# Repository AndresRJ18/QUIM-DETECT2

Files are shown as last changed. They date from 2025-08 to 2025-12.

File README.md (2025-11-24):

# QUIM-DETECT2  🍓🍓🍓
### Sistema Portátil de Detección de Pesticidas en Fresas mediante Espectroscopía VIS/NIR  

**QUIM-DETECT2** es un proyecto de investigación aplicada orientado al desarrollo de un **dispositivo portátil, económico y no destructivo** para la detección del pesticida organofosforado **Profenofos** en fresas, utilizando **espectroscopía de reflexión VIS/NIR (350–1000 nm)** y **análisis multivariante con Machine Learning**.  

El proyecto se alinea con el **Objetivo de Desarrollo Sostenible (ODS) 12: Producción y Consumo Responsables**, específicamente con la meta 12.4, cual busca reducir los impactos negativos de sustancias químicas peligrosas a lo largo de su ciclo de vida., promoviendo la gestión ecológica de productos químicos agrícolas y la reducción de riesgos para la salud humana y el medio ambiente.  

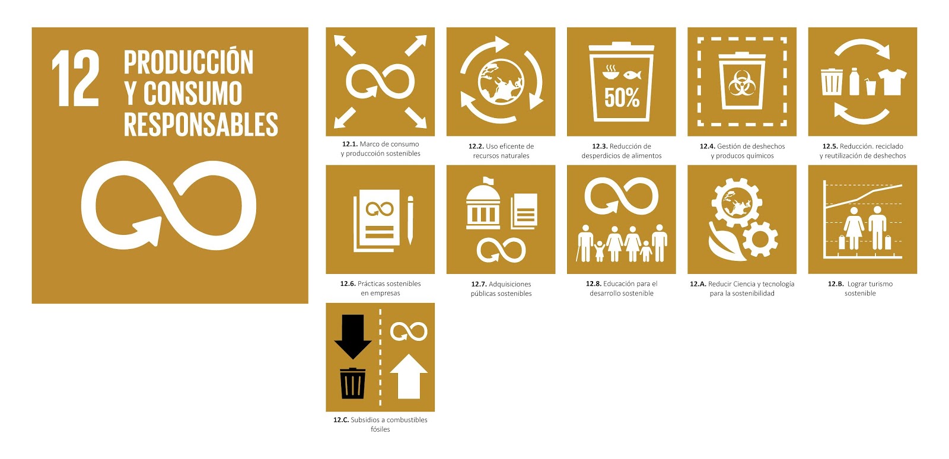
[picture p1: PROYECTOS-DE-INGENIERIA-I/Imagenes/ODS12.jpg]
ODS12


---

## 🎯 Objetivo General  

Desarrollar un **sistema portátil de bajo costo** capaz de identificar la presencia de residuos de *Profenofos* en fresas mediante la caracterización de su huella espectral.

---

## ⚙️ Componentes Principales  

- **Sensor óptico:** AS7343 (VIS/NIR 350–1000 nm, 18 canales espectrales).  
- **Módulo mecánico:** Servomotor y motor a paso para rotación controlada de la fresa y promediado espectral.  
- **Calibración:** Placa de teflón blanco (~97% reflectancia) o superficie blanca estandarizada.  
- **Carcasa y óptica:** Caja rígida con sellado óptico, ventana desmontable y compartimentos separados para electrónica y óptica.  
- **Procesamiento:** Algoritmos de Machine Learning (SVM, Random Forest, ANN) para clasificación de muestras contaminadas vs. no contaminadas.  

---

## 🧠 Metodología  

1. **Captura espectral:** Adquisición multicanal en el rango 400–1050 nm.  
2. **Preprocesamiento:** Filtrado de ruido, normalización, PCA y eliminación de outliers.  
3. **Entrenamiento ML:** Modelos supervisados para detección de residuos de *Profenofos*.  
4. **Validación:** Comparación frente a espectrómetros comerciales (PS-100, Apogee Instruments) y referencias científicas (*Soltani Nazarloo et al., 2021*).  

---

## 🧩 Diseño del Sistema  

- Diseño **modular** y de **mantenimiento rápido**.  
- **Ventana óptica desmontable** para limpieza y reemplazo.  
- **Superficies lisas y sellado óptico** para evitar contaminación de luz o humedad.  
- **Protección eléctrica** mediante fusibles y aisladores.  
- **Soporte fijo** con servomotor que mantiene distancia constante entre la muestra y el sensor.  

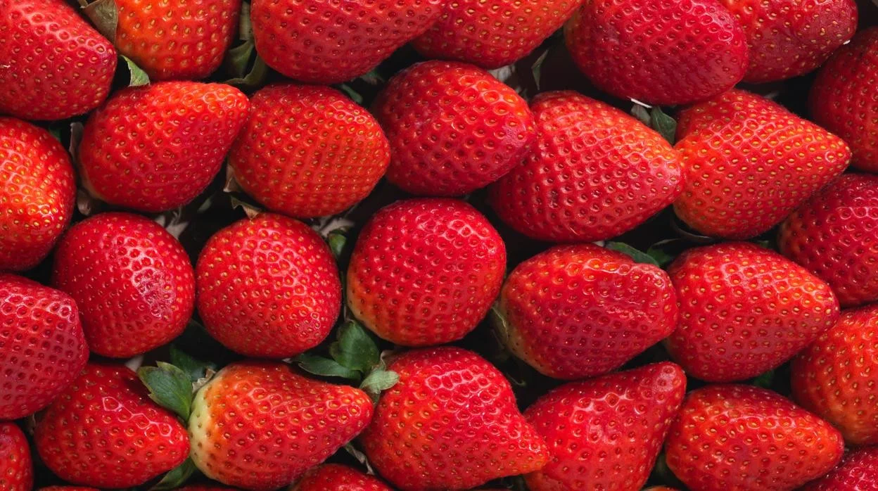
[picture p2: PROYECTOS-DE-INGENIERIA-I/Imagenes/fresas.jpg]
Fresas


---

## 🧪 Referencias Científicas  

- Soltani Nazarloo, A., et al. (2021). *Feasibility of Using VIS/NIR Spectroscopy and Multivariate Analysis for Pesticide Residue Detection in Tomatoes.*  
- Apogee Instruments PS-100 – Compact VIS/NIR Spectrometer (350–1100 nm).  

---

## 👥 Equipo de Trabajo  

- **Matias Dario Huerta Cruz**  
- **Andres Steven Rodas Janampa**  
- **Jorge Esteban Roldan Montalvan**  
- **Juan Diego Lopez Vega**  
- **Camilla Vanessa Pacora Mendoza**  

---

## 🎓 Proyecto Académico  

Proyecto desarrollado para el curso **Proyectos de Ingeniería I – 2025-II**  
**Universidad Peruana Cayetano Heredia (UPCH)**  
Facultad de Ciencias e Ingeniería – **Carrera de Ingeniería Informática**

---

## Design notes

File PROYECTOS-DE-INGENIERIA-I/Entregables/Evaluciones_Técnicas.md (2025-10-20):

#  Análisis Tecnológico 

| **Subfunción** | **Boceto 1 – Cámara multiespectral** | **Boceto 2 – Escáner UV con pantalla** | **Boceto 3 – Sistema AS7343 con caja giratoria** |
|---|---|---|---|
| **Rotar fresa / toma de muestra** | No aplica (captura fija) | Sin movimiento | Motor paso a paso con brazo rotable |
| **Detección** | Cámara multiespectral de alta gama | LED UV + fotodiodo TEMP6000 | Sensor AS7343 visible/NIR |
| **Control y adquisición** | Raspberry Pi | ESP32 | Arduino Nano 33 IoT |
| **Procesamiento de datos** | Software propietario | Pantalla LCD con lógica simple | Google Colab (Python) |
| **Energía** | Batería Li-ion 7.4V | Batería recargable 5V | Batería 18650 |

---

##  Criterios de Evaluación Tecnológica

| **Criterio** | **Peso** |
|---|---|
| Precisión de medición | 0.30 |
| Costo total | 0.25 |
| Complejidad técnica (menor = mejor) | 0.15 |
| Mantenimiento y calibración | 0.15 |
| Robustez y fiabilidad | 0.10 |
| Consumo energético | 0.05 |
| **Total** | **1.00** |

---

###  Ponderación de los 3 Bocetos

| **Criterio** | **Peso** | **Boceto 1** | **Boceto 2** | **Boceto 3** | **P*B1** | **P*B2** | **P*B3** |
|---|---|---|---|---|---|---|---|
| Precisión | 0.30 | 5 | 3 | 4 | 1.50 | 0.90 | 1.20 |
| Costo | 0.25 | 1 | 4 | 5 | 0.25 | 1.00 | 1.25 |
| Complejidad | 0.15 | 2 | 3 | 4 | 0.30 | 0.45 | 0.60 |
| Mantenimiento | 0.15 | 3 | 4 | 4 | 0.45 | 0.60 | 0.60 |
| Robustez | 0.10 | 3 | 3 | 4 | 0.30 | 0.30 | 0.40 |
| Consumo | 0.05 | 2 | 3 | 4 | 0.10 | 0.15 | 0.20 |
| **Total ponderado** | — | — | — | — | **2.90** | **3.40** | **4.25** |

---

# Análisis Económico

Este análisis compara los **costos estimados** de los tres bocetos desarrollados durante la fase de diseño.  
Los precios están expresados en **soles peruanos (S/.)**, basados en componentes disponibles localmente.

| *Boceto* | *Material / Tipo* | *Costo (S/.)* |
|---|---|---|
| **Boceto 1 – Cámara multiespectral** | Sensor óptico de alta gama | 3040 |
|  | Electrónica + carcasa plástica | 240 |
|  | Batería Li-ion 7.4V | 95 |
|  | Carcasa de fibra de vidrio | 115 |
|  | Lentes ópticos | 380 |
| **➡ TOTAL BOCETO 1** | | **3,870** |
| | | |
| **Boceto 2 – Escáner UV con pantalla** | Placa ESP32 (PCB) | 45 |
|  | LED UV | 15 |
|  | Fotodiodo TEMP6000 | 30 |
|  | Pantalla LCD táctil | 140 |
|  | Batería recargable 5V | 40 |
|  | Botones + interruptor | 20 |
| **➡ TOTAL BOCETO 2** | | **290** |
| | | |
| **Boceto 3 – Sistema AS7343 con caja giratoria** | Arduino Nano 33 IoT | 30 |
|  | Sensor AS7343 | 87 |
|  | LED UV | 15 |
|  | Protoboard PCB | 12 |
|  | Batería 18650 | 30 |
|  | Motor paso a paso | 40 |
| **➡ TOTAL BOCETO 3** | | **214** |

---

##  Comparación Global

| **Boceto** | **Costo total (S/.)** | **Puntaje tecnológico** | **Conclusión** |
|---|---|---|---|
| **Boceto 1** | 3,870 | 2.90 | Demasiado costoso; poca viabilidad económica. |
| **Boceto 2** | 290 | 3.40 | Económico pero de baja precisión espectral. |
| **Boceto 3** | **214** | **4.25** | **Ganador: equilibrio óptimo entre costo, precisión y simplicidad.** |

---

##  Conclusión Final

Tras los análisis **tecnológico y económico**, el **Boceto 3 – Sistema AS7343 con caja giratoria automatizada** resulta ser la opción **más viable y eficiente** para el proyecto **QUIM-DETECT2**.

**Ventajas clave:**
- Alta **relación costo/beneficio**.  
- **Automatización controlada por Arduino** y fácil integración con Colab.  
- **Sensor AS7343** con amplio rango espectral visible/NIR.  
- Bajo consumo energético y mantenimiento simple.

**Resultado final:**
>  **Boceto 3 es el diseño seleccionado para la etapa de prototipo funcional.**

---

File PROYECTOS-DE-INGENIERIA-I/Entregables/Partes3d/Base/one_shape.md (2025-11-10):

https://cad.onshape.com/documents/9d8c01df3c8119e925cbea9b/w/a2362c5ac7091070a72aa14c/e/2f6126760c83169a9e7941d2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

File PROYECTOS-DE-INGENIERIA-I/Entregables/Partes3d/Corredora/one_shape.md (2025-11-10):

https://cad.onshape.com/documents/294b85e7c07487fa4451a9e6/w/659b38d2539dfde506b91bc1/e/4ee9894ba0a7f4cce7f5a1a7

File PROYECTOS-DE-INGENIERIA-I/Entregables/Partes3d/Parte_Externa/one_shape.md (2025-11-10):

https://cad.onshape.com/documents/a73c0aeb384fb46d6d2fbee9/w/264d6408a676414e0042c754/e/2a0a6357fcb5855a3a05d3cd

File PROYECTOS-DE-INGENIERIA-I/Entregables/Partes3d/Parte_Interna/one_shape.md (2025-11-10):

https://cad.onshape.com/documents/812638d14859d3e0c73471cd/w/76fb96b3589037339beacf50/e/4947845a3cf110dcae4a0abb

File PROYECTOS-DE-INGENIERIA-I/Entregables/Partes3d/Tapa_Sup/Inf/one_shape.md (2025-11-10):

https://cad.onshape.com/documents/21cbaf00370e452b56931cd7/w/389134fb3a4c880b168e743d/e/24faa405fc58d7c6c260f44f

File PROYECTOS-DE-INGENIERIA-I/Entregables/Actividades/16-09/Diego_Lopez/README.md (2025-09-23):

# Proyecto: Predicción de PM10 en estaciones de monitoreo

## 📌 Descripción
Este proyecto tiene como objetivo **predecir la concentración diaria de PM10** en distintas estaciones de monitoreo utilizando **regresión lineal**.  
Se trabajó con datos de los años **2023, 2024 y 2025**, aplicando técnicas de ingeniería de características y evaluación de modelos.

---

## ⚙️ Metodología

### 1. Lectura y unión de datos
Se cargaron los datasets de 2023, 2024 y 2025, y se unieron en un único `DataFrame` para facilitar el preprocesamiento.

### 2. Procesamiento de fechas
Se extrajeron variables temporales relevantes:
- `year`, `month`, `dayofweek`, `dayofyear`.

### 3. Codificación de estaciones
Se utilizó **OneHotEncoder** para transformar la variable categórica **Site ID** en variables binarias.  
- Se entrenó el encoder con **2023–2024** para evitar fugas de información.  
- Se incluyó la opción `handle_unknown="ignore"` para que nuevas estaciones en 2025 no generaran errores.

### 4. Creación de variables de retraso (lags)
Se generaron variables que representan el historial de contaminación en la misma estación:
- `PM10_lag1`: día anterior.  
- `PM10_lag7`: una semana antes.  
- `PM10_lag30`: un mes antes.  

Estas variables permiten que el modelo tenga **memoria temporal**.

### 5. Representación cíclica de variables de tiempo
Mes, día de la semana y día del año se transformaron en componentes **seno y coseno** para capturar su **naturaleza cíclica**:
- `month_sin`, `month_cos`  
- `dow_sin`, `dow_cos`  
- `doy_sin`, `doy_cos`  

Esto evita que el modelo interprete de forma incorrecta el paso de diciembre (12) a enero (1).

### 6. Definición de variables de entrada
El conjunto de features incluyó:
- Lags de PM10.  
- Variables cíclicas de tiempo.  
- Variables one-hot de las estaciones.  

### 7. Eliminación de valores faltantes
Se eliminaron las primeras filas de cada estación que no podían tener lags (por ejemplo, no existe `PM10_lag7` para los primeros 7 días).

### 8. División de los datos
- **Train:** 2023  
- **Test:** 2024  
- **Future:** 2025  

### 9. Entrenamiento
Se entrenó un **modelo de regresión lineal** con los datos de 2023.

### 10. Evaluación
- **Validación en 2024 (test)**: se midió qué tan bien generaliza el modelo a un año futuro.  
- **Evaluación en 2025 (futuro)**: se compararon predicciones con los datos reales de 2025.

---

## 📊 Resultados

### Evaluación en 2024
```tex
MSE: 289.39
RMSE: 17.01
R²: 0.44
```
### Evaluación en 2025
```text
MSE: 239.74
RMSE: 15.48
R²: 0.38
```

## 📝 Conclusiones

1. **Rendimiento del modelo**:  
   - El modelo de regresión lineal logra capturar parte de la variabilidad del PM10 en los años 2024 y 2025, con un R² moderado (0.44 en 2024 y 0.38 en 2025).  
   - El RMSE indica un error promedio de predicción de ~17 µg/m³ en 2024 y ~15.5 µg/m³ en 2025.

2. **Interpretación de los resultados**:  
   - Aunque el R² disminuye ligeramente en 2025, el modelo sigue siendo capaz de reflejar tendencias generales de PM10.  
   - La reducción del RMSE en 2025 sugiere menor variabilidad en los datos de ese año o que las variables de retraso y cíclicas ayudaron a mejorar la precisión.

3. **Fortalezas**:  
   - Uso de variables de retraso (lags) que permiten incorporar memoria temporal.  
   - Representación cíclica de tiempo que evita problemas con variables como mes o día de la semana.  
   - Manejo de nuevas estaciones en 2025 gracias a `handle_unknown="ignore"` en OneHotEncoder.

4. **Limitaciones y mejoras futuras**:  
   - El modelo lineal puede no capturar relaciones no lineales complejas entre las variables.  
   - Se podrían explorar modelos más avanzados (Random Forest, Gradient Boosting o redes neuronales) para mejorar R² y reducir el RMSE.  
   - Incorporar variables meteorológicas y contaminantes adicionales podría aumentar la capacidad predictiva.

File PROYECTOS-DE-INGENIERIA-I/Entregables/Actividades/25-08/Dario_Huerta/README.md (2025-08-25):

## Tarea 25/08
# SimScale 
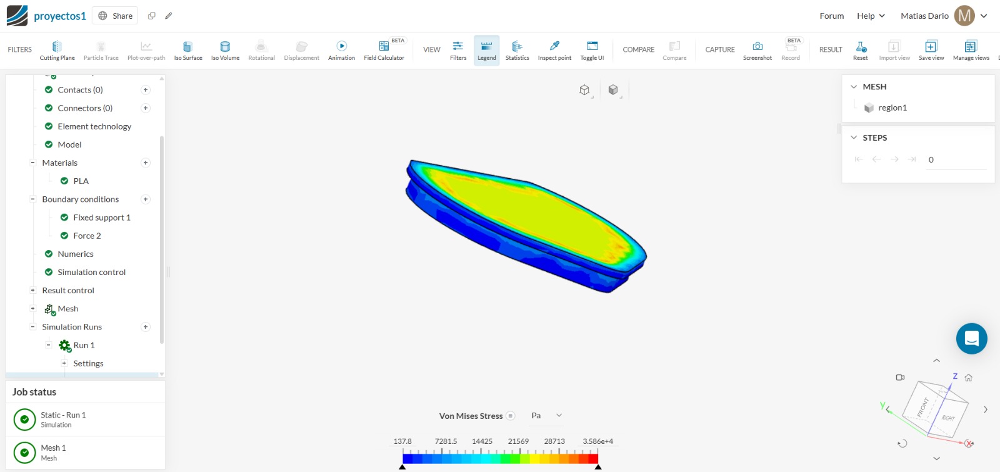
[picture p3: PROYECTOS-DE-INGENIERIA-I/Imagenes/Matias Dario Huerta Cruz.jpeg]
Matias Dario Huerta Cruz


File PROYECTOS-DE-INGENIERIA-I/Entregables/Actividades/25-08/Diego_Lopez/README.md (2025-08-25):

## Tarea 25/08
# SimScale

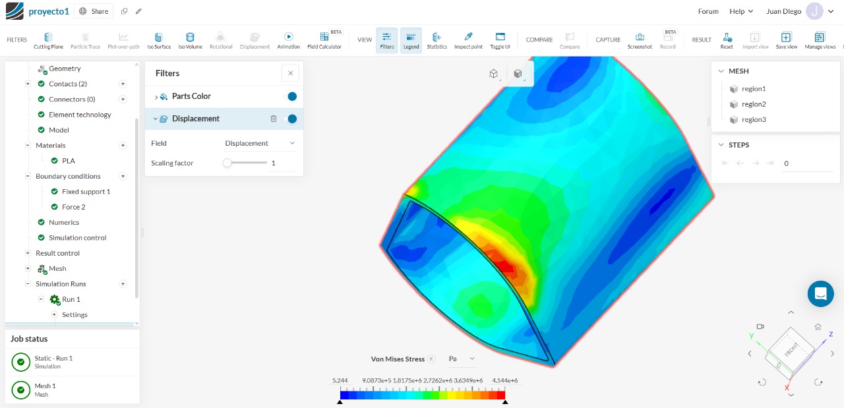
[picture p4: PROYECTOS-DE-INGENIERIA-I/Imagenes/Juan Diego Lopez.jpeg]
Juan Diego Lopez


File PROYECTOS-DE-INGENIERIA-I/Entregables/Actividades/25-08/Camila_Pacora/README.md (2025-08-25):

## ACTIVIDAD 25/08
# SimScale 

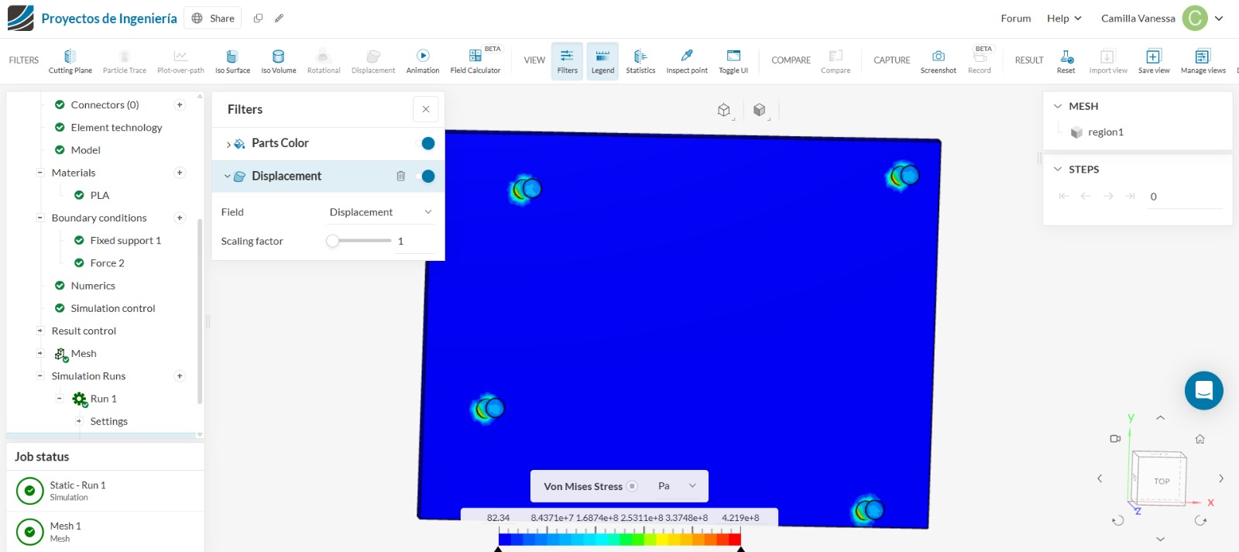
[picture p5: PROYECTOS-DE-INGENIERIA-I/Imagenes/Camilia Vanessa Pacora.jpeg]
Camila Pacora


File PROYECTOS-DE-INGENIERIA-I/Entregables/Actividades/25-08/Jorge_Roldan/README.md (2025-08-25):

## ACTIVIDAD 25/08
# SimScale 

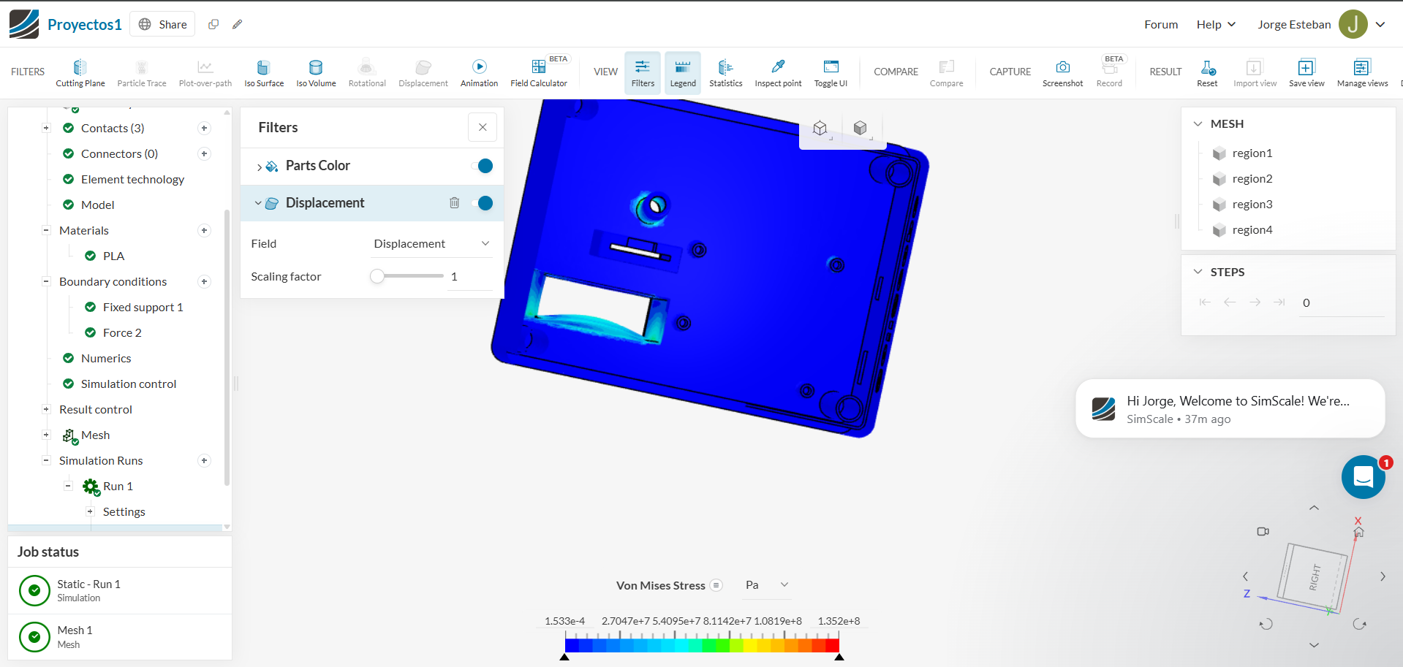
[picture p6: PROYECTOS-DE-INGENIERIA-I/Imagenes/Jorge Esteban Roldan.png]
Caja Negra


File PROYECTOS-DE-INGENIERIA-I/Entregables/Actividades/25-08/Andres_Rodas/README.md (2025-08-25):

## ACTIVIDAD 25/08
# SimScale 

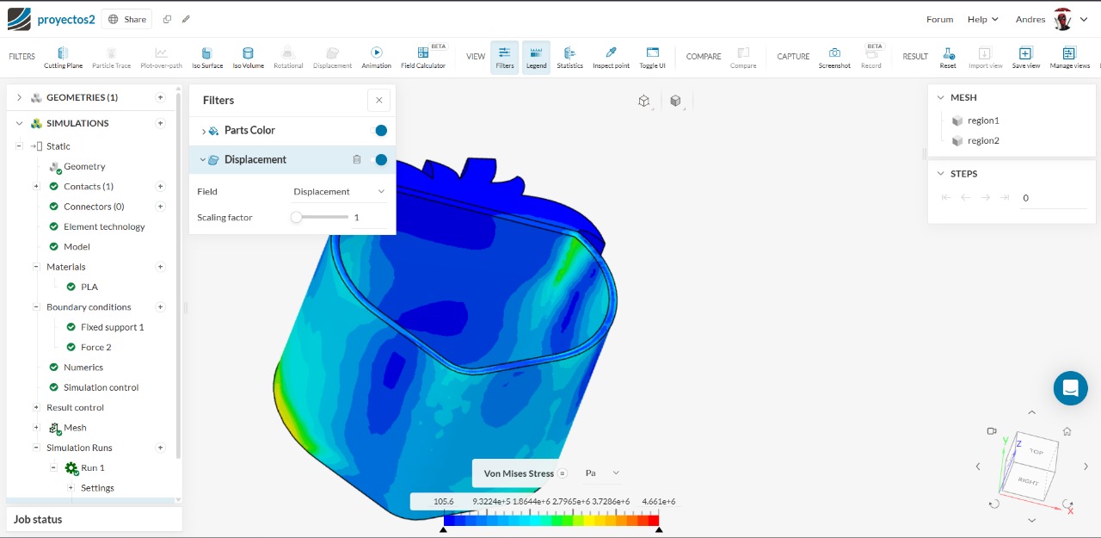
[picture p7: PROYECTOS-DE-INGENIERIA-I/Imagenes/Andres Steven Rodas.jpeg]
Caja Negra


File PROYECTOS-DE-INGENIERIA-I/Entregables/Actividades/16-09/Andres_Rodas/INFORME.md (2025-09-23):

# 📊 Predicción de Contaminación del Aire en Florida (2023–2025)

## 📌 Introducción  
El presente trabajo busca **analizar y predecir la concentración diaria de PM10** en Florida utilizando datos de los años **2023, 2024 y 2025**.  
Se aplicaron técnicas de **aprendizaje automático supervisado** para evaluar qué tan bien un modelo podía anticipar los valores de 2025 basándose en los años previos.  

---

## 🛠️ Herramientas y Librerías Utilizadas  
- **Python** como lenguaje principal.  
- **Pandas & NumPy** → limpieza, manipulación y análisis de datos.  
- **Matplotlib & Seaborn** → visualización exploratoria (KDE, pairplots, histogramas).  
- **Scikit-learn** → modelos y métricas.  
  - `LinearRegression` → modelo predictivo base.  
  - `SimpleImputer` → manejo de valores faltantes.  
  - `get_dummies` → codificación de variables categóricas.  

---

## ⚙️ Metodología  
1. **Unión de datasets (2023, 2024, 2025)**.  
2. **Preprocesamiento de fechas**: se generaron variables como `Year`, `Month`, `Day` y `Days_Since_Start`.  
3. **Separación de variables**:  
   - *Numéricas*: latitud, longitud, días, códigos, etc.  
   - *Categóricas*: fuente, estado, condado, etc. (transformadas con *one-hot encoding*).  
4. **Imputación de valores faltantes** mediante la mediana.  
5. **Descartamos columnas como `Daily AQI Value` y `Daily Obs Count`**.  
   - Estas columnas estaban **fuertemente relacionadas con el target (`Daily Mean PM10 Concentration`)**.  
   - En Machine Learning, incluirlas generaría *data leakage*, ya que el modelo tendría información demasiado directa sobre lo que queremos predecir.  
6. **División de datos**:  
   - Entrenamiento → 2023 y 2024.  
   - Prueba → 2025.  
7. **Entrenamiento de modelo de Regresión Lineal**.  
8. **Evaluación con métricas**:  
   - MAE (Error Medio Absoluto)  
   - RMSE (Raíz del Error Cuadrático Medio)  
   - R² (Coeficiente de Determinación)  

---

## 📈 Resultados  
El modelo logró realizar predicciones sobre los datos de 2025.  
Sin embargo, el valor de **R² fue bajo**, lo que indica que la regresión lineal **no explica completamente la variabilidad de los datos**.

**Métricas de evaluación (2025):**
- **MAE**: qué tan lejos estuvo, en promedio, de los valores reales.  
- **RMSE**: penaliza más los errores grandes.  
- **R²**: porcentaje de variabilidad explicada por el modelo.  

---

## ✅ Ventajas  
- Implementación sencilla y rápida.  
- Modelo base **fácil de interpretar**.  
- Pipeline reproducible y aplicable a otros conjuntos de datos.  

## ⚠️ Desventajas  
- La regresión lineal **no captura relaciones no lineales**.  
- El *one-hot encoding* genera demasiadas columnas cuando hay muchas categorías.  
- No se incluyeron factores externos importantes (clima, estaciones, tráfico).  
- Resultados poco satisfactorios en métricas de ajuste.  

---

## 🔧 Posibles Mejoras  
- Probar modelos más complejos: **Random Forest, Gradient Boosting, Redes Neuronales**.  
- Incluir variables externas (clima, humedad, viento).  
- Aplicar **regularización (Ridge/Lasso)** para mejorar la generalización.  
- Selección de características y reducción de dimensionalidad.  
- Implementar técnicas específicas para **series temporales** (ARIMA, Prophet, LSTM).  

---

## 📌 Conclusión  
Este proyecto sirvió como **primer acercamiento al modelado predictivo de la calidad del aire**.  
Aunque los resultados no fueron los esperados, el proceso permitió:  
- Explorar y limpiar datos.  
- Construir un pipeline reproducible.  
- Identificar las limitaciones de un modelo lineal.  
- Aprender la importancia de **evitar data leakage**: descartar variables como *Daily AQI Value* y *Daily Obs Count* que estaban demasiado relacionadas con el target.  

El siguiente paso será **probar modelos no lineales y métodos especializados en series de tiempo** para mejorar la capacidad predictiva.  

El siguiente paso será **probar modelos no lineales y métodos especializados en series de tiempo** para mejorar la capacidad pred

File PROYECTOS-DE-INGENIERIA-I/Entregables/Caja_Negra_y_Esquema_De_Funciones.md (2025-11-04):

# 📦Caja Negra 
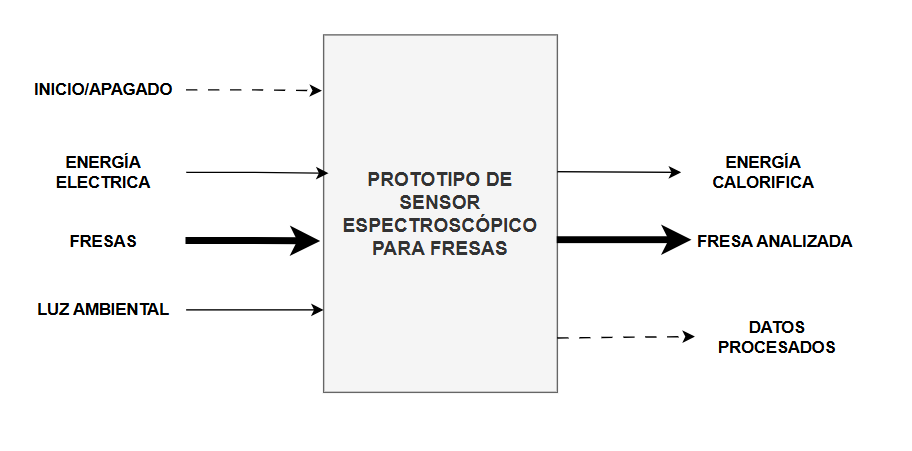
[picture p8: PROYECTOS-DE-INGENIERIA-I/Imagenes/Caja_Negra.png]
Caja Negra


🔗 [Ver en Draw.io](https://app.diagrams.net/#G1jx3XUJulqEHMiZ95NdmwGDe8fgNdj5zd#%7B%22pageId%22%3A%22B8XTpHp7p6XBmzQAhsuS%22%7D)

# 📱 Caja Negra – App TanoSpectra
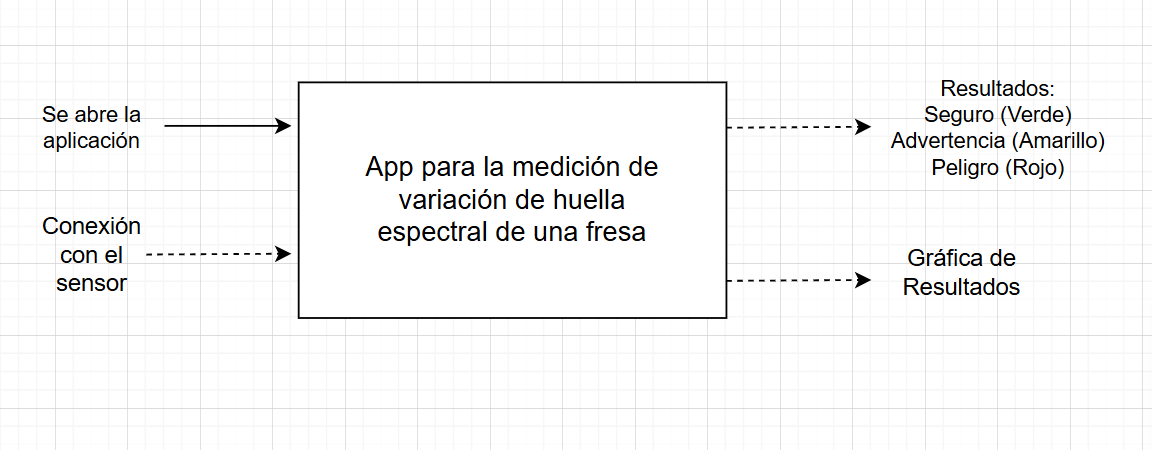
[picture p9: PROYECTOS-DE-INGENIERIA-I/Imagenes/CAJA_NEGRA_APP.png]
Caja Negra App
  

🔗 [Ver en Draw.io](https://app.diagrams.net/#G1rWM1FSlPOJzXhhvO3CIIONgmZpNr90bF#%7B%22pageId%22%3A%22U6wzN8fkbURlSwQlV9s4%22%7D)

# ⚙️Esquema de Funciones 
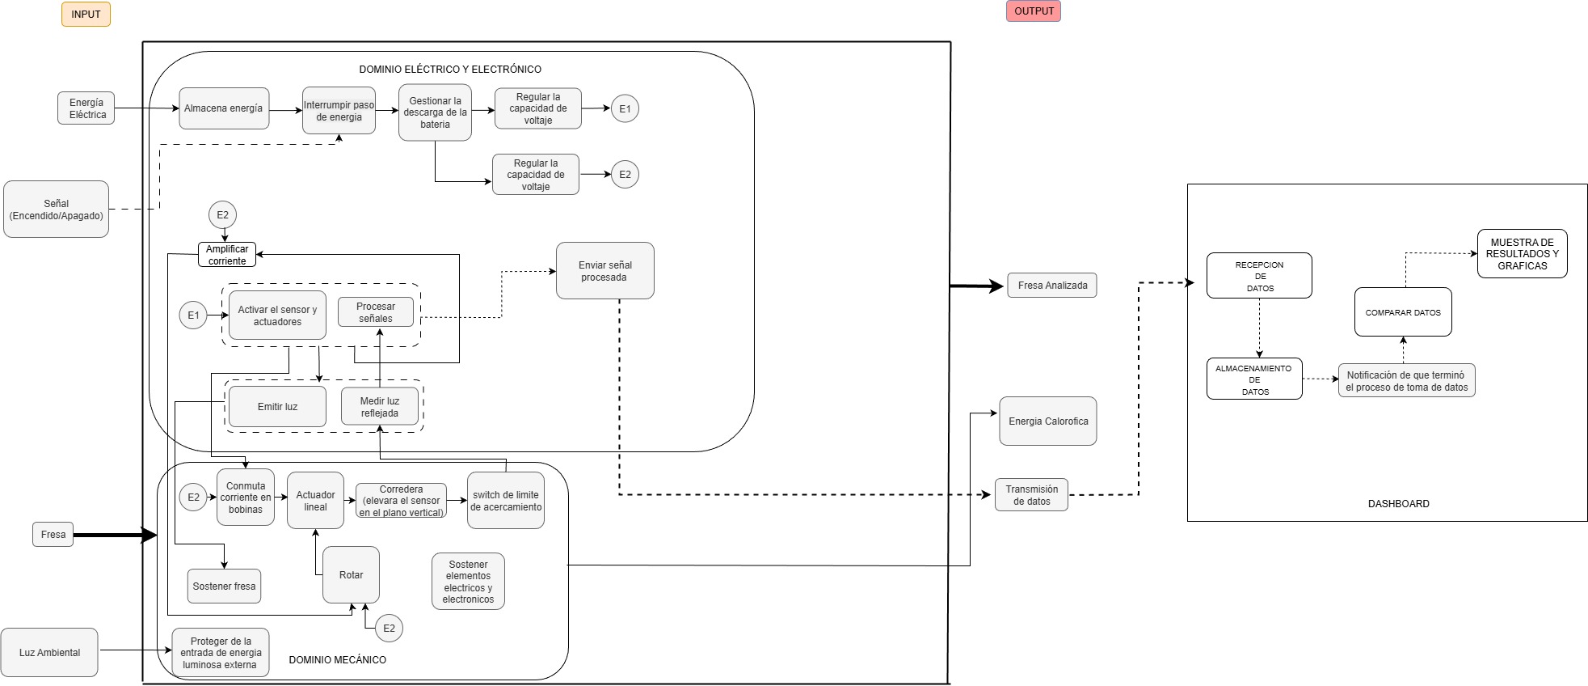
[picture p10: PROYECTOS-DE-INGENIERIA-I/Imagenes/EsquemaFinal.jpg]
Esquema de Funciones


🔗 [Ver en Draw.io](https://app.diagrams.net/#G1iHN4fA3m1PzcGaVWDI4e6vaWyWay0yBb#%7B"pageId"%3A"qVbb3z2iEFRG91X4rkYl"%7D)

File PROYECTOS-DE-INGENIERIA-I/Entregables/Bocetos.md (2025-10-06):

# 📦 Bocetos del Proyecto de Detección de Pesticidas en Fresas

En esta sección se presentan los **tres bocetos desarrollados** durante la fase de diseño del dispositivo.  
Cada propuesta busca detectar la presencia de **profenofos** en fresas mediante técnicas ópticas, priorizando la **portabilidad**, **bajo costo** y **facilidad de uso en campo**.

---

## 🧩 **Boceto 1 – Caja con cámara multiespectral**

**Descripción:**  
Prototipo inicial basado en una **cámara multiespectral profesional** dentro de una caja cerrada para aislar la luz ambiental.  
El sistema captura la firma espectral completa del fruto, ofreciendo alta precisión.

**Ventajas:**  
- Alta calidad y resolución espectral.  
- Resultados científicos muy precisos.  

**Desventajas:**  
- **Costo elevado** de los sensores multiespectrales (fuera del alcance de pequeños productores).  
- Difícil mantenimiento y calibración.  

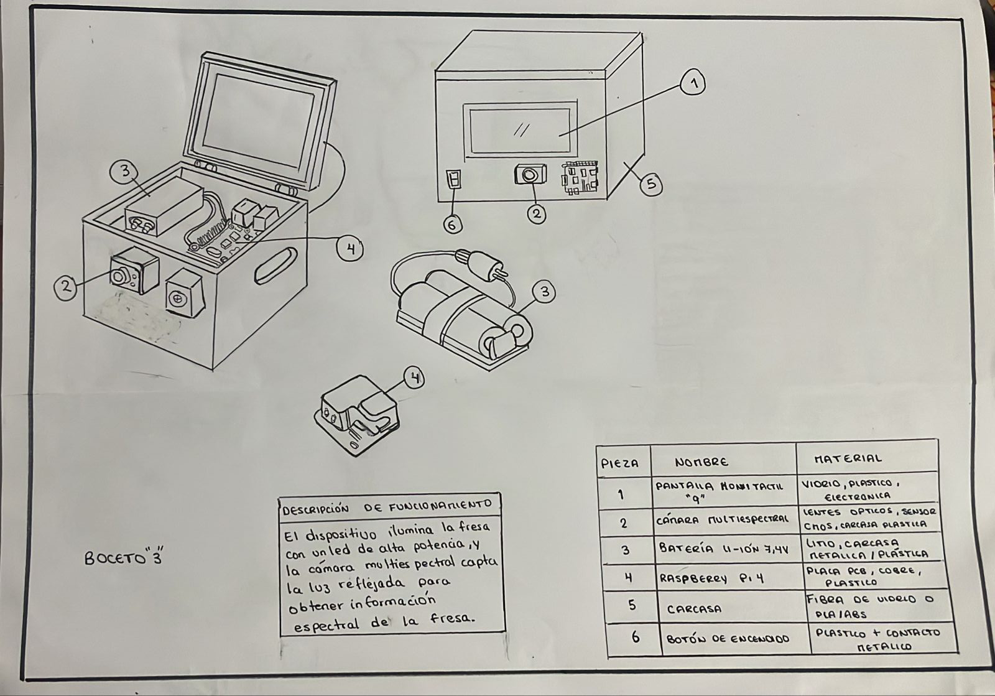
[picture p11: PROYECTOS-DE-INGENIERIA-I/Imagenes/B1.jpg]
B1


**Conclusión:**  
Fue descartado por su alto costo, aunque sirvió como referencia teórica para definir los rangos espectrales ideales.

---

## 💡 **Boceto 2 – Escáner espectral con luz UV y pantalla integrada**

**Descripción:**  
Dispositivo tipo **escáner portátil**, inspirado en un lector de documentos, que **emite luz ultravioleta (UV)** sobre la superficie de la fresa.  
Incluye una **pequeña pantalla** que muestra resultados instantáneos de contaminación.

**Ventajas:**  
- Interfaz visual directa.  
- Diseño atractivo y ergonómico.  

**Desventajas:**  
- Requiere componentes UV y pantalla de alto costo.  
- Mayor consumo energético y complejidad electrónica.  

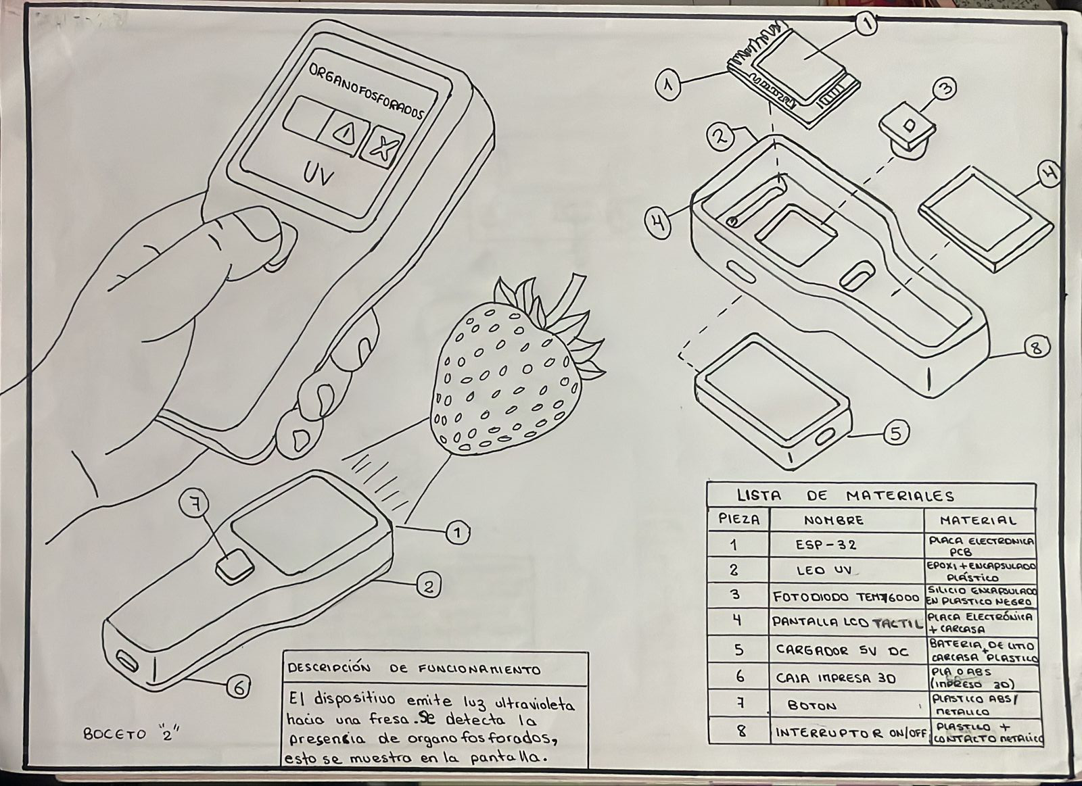
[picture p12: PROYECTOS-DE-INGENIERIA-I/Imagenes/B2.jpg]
B2


**Conclusión:**  
Aunque innovador, su precio y mantenimiento limitan su aplicación práctica en campo.

---

## 🍓 **Boceto 3 – Sistema espectral AS7343 con caja giratoria (Versión actual)**

**Descripción:**  
Diseño final y **versión actualmente en desarrollo**, basado en el **sensor espectral AS7343**, que trabaja en el rango **VIS/NIR (350–1000 nm)**.  
El sistema incluye una **caja protectora opaca** para evitar interferencias de luz externa y un **motor que rota la fresa** para obtener lecturas desde diferentes ángulos.  

**Ventajas:**  
- Sensor de **bajo costo y buena sensibilidad espectral**.  
- **Diseño portátil**, estable y fácil de limpiar.  
- Ideal para entornos agrícolas y pruebas de campo.  

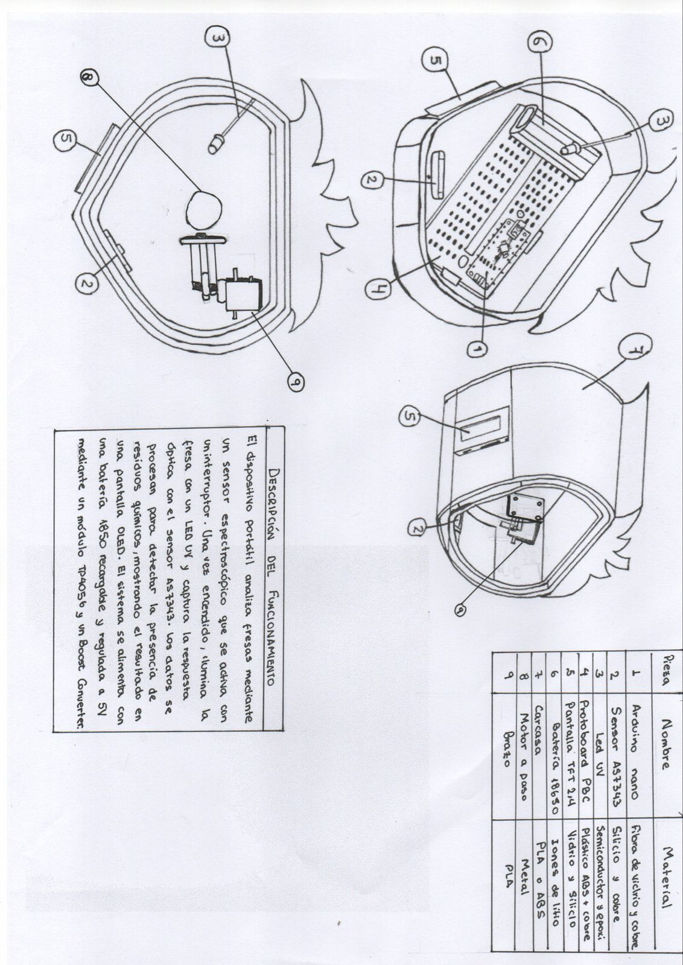
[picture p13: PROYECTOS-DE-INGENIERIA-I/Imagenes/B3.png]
B3


**Conclusión:**  
Seleccionado como **modelo final** por su equilibrio entre precisión, accesibilidad y costo.  
Representa una solución práctica para la detección de residuos de profenofos en frutas.

---

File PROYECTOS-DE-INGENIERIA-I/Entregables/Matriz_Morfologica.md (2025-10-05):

# 🧩 Matriz Morfológica

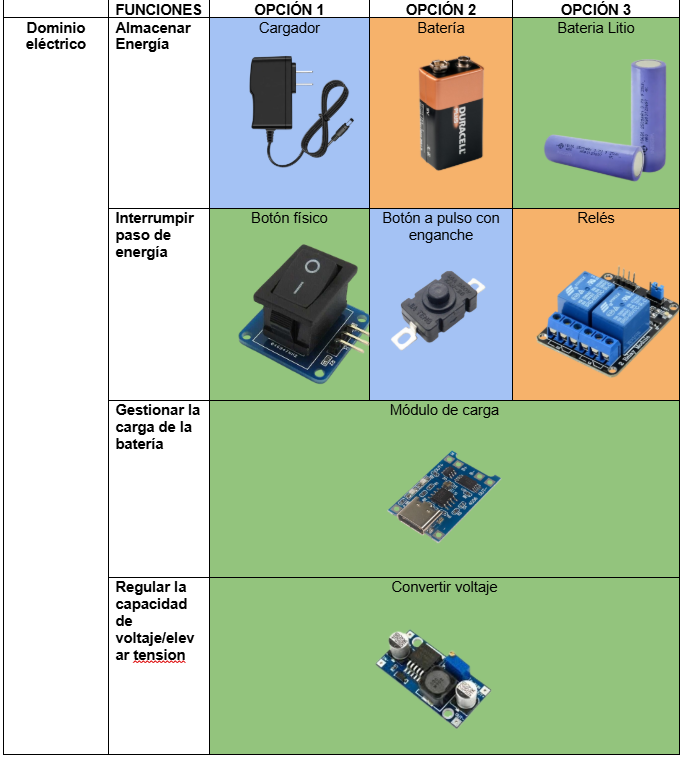
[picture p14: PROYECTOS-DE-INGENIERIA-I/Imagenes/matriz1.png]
matriz1


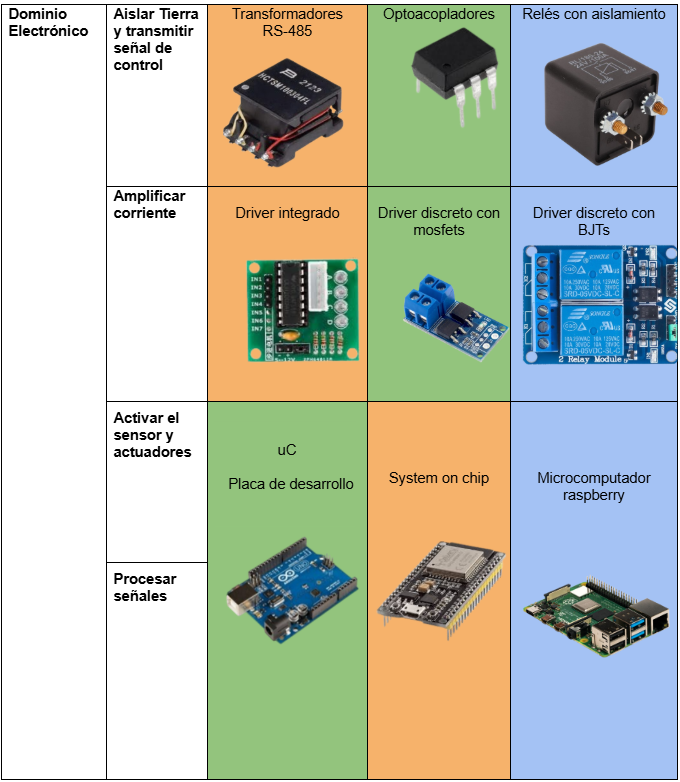
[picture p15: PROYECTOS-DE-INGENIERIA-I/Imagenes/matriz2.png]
matriz2


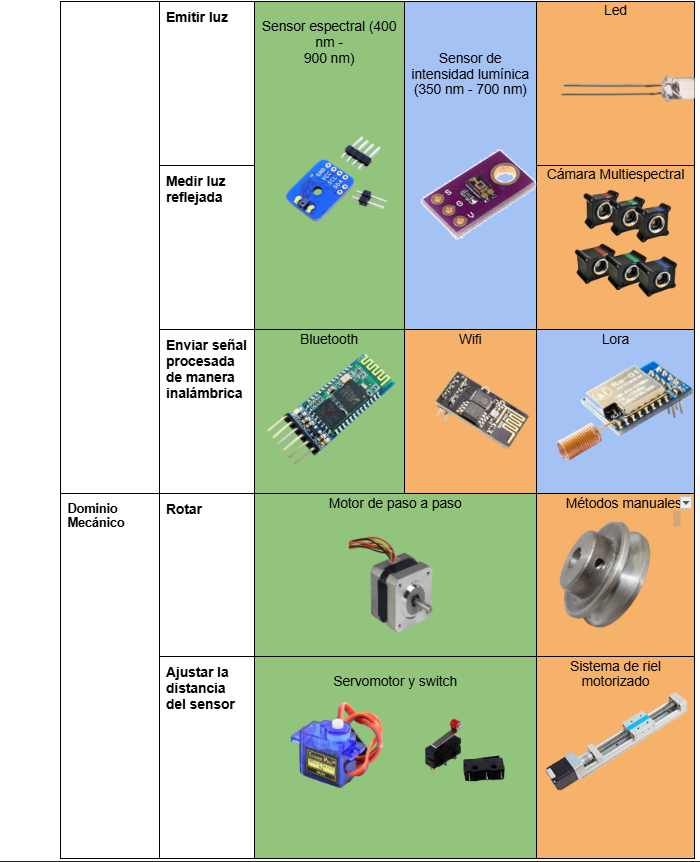
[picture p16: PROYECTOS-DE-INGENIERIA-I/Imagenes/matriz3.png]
matriz3


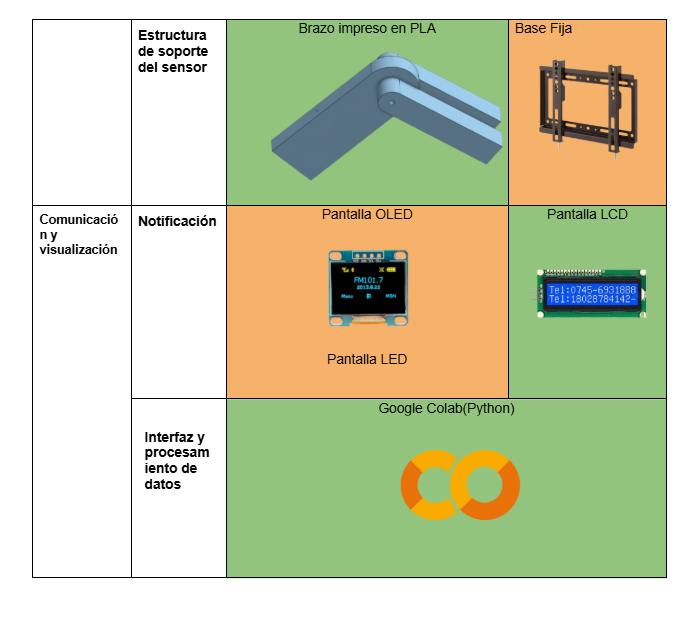
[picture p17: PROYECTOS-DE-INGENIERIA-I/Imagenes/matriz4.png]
matriz4


---

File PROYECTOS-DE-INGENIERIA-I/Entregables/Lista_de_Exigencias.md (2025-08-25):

# Lista de Exigencias – *QUIM DETECT*

| **Proyecto** | Diseño y desarrollo de un sistema para la detección de variaciones en la huella espectral de fresas mediante espectroscopía y análisis multicanal | **Fecha:** 19/08/25 |
|---|---|---|
| **Cliente**  | Universidad Peruana Cayetano Heredia | **Edición:** Rev. 3 |
| **Elaborado**| Dario Huerta, Jorge Roldan, Juan López, Andrés Rodas, Camilla Pacora | |

| Fecha | Tipo | Exigencia / Deseo | Descripción | Responsable |
|---|---|---|---|---|
| 18/08/25 | E | Función Principal | Detectar variaciones en la huella espectral de fresas mediante análisis multicanal y técnicas de procesamiento, con el fin de identificar posibles residuos químicos y contribuir a la prevención de riesgos para la salud del consumidor. | JL, DH, JR |
| 18/08/25 | E | Hardware | El sistema debe integrar los dispositivos necesarios para adquisición de datos , imagenes,señales, frecuencia y control de iluminación, incluyendo un mecanismo que permita rotación o movimiento controlado de las muestras para garantizar cobertura completa. Se exige geometría y repetibilidad, estabilidad en la adquisición, separación de señales, alimentación regulada y bajo ruido.| JL, DH, JR |
| 25/08/25 | D | Control | El software debe permitir el inicio y control del sistema de manera general. | JL, AR |
| 25/08/25 | D | Adquisición de Datos | El software debe capturar los datos de forma consistente y verificable, asegurando que no se pierdan mediciones. | JL, AR |
| 25/08/25 | D | Procesamiento de Señales | El software debe procesar los datos para obtener resultados confiables y repetibles, incluyendo validaciones básicas y filtrado general de información. | JL, AR |
| 25/08/25 | D | Comunicación | El software debe transmitir los datos de manera estructurada a un módulo receptor o almacenamiento externo, asegurando integridad y consistencia. | JL, AR |
| 25/08/25 | D | Registro y Trazabilidad | El software debe registrar todos los datos y acciones relevantes para asegurar trazabilidad y seguimiento. | JL, AR |
| 25/08/25 | D | Interfaz | El software debe ofrecer una interfaz clara y accesible que permita supervisión y control general del sistema por parte del usuario. | JL, AR |
| 26/08/25 | E | Evaluación | El sistema debe permitir realizar análisis espectrales y preprocesamiento de datos para evaluar la presencia de residuos químicos de manera confiable. | AR, CP |
| 01/09/25 | E | Selección | Implementación de métodos de aprendizaje automático para clasificación de resultados basados en los datos adquiridos. | JL |
| 08/09/25 | E | Visualización | Generación de representaciones gráficas y mapas de los datos obtenidos para facilitar interpretación de resultados. | JR, DH |

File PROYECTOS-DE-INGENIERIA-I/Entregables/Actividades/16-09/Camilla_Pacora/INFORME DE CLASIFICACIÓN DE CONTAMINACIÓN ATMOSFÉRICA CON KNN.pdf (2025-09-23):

INFORME DE CLASIFICACIÓN DE CONTAMINACIÓN ATMOSFÉRICA CON KNN

1. Introducción
La contaminación atmosférica por material particulado (PM10) constituye un problema relevante de salud pública, dado que concentraciones elevadas pueden ocasionar efectos adversos en la salud respiratoria y cardiovascular. En este trabajo se utiliza el algoritmo K-Nearest Neighbors (KNN) para clasificar los registros diarios de concentración de PM10 en función de un umbral de calidad del aire.
Se emplean los registros diarios de 2023 y 2024 obtenidos de la Agencia de Protección Ambiental de los Estados Unidos (EPA), los cuales se combinaron en un solo conjunto de datos para entrenamiento y prueba del modelo. Posteriormente, los registros de 2025 se utilizan como conjunto de validación externa.
2. Metodología
2.1. Preparación de los datos
- Se cargaron tres archivos en formato CSV correspondientes a los años 2023, 2024 y 2025.
- Se unificaron los datos de 2023 y 2024 en un único DataFrame, eliminando duplicados y asegurando la consistencia en las variables.
- Se seleccionaron las siguientes variables predictoras:
- Daily Mean PM10 Concentration (µg/m³)
- Daily AQI Value
- Percent Complete
- Site Latitude
- Site Longitude
- Se creó una variable binaria llamada TARGET CLASS, con el siguiente criterio:
2.2. Normalización

Dado que KNN se basa en distancias, todas las variables predictoras fueron escaladas mediante StandardScaler, con media cero y varianza unitaria.
2.3. División del dataset
El conjunto de 2023-2024 se dividió en:
- 70% entrenamiento
- 30% prueba
2.4. Entrenamiento del modelo
- Se entrenó un modelo de KNN con k=10k=10k=10 vecinos.
- Se evaluó el desempeño mediante matriz de confusión y reportes de precisión, recall y F1-score.
- Se aplicó el método del codo (elbow method) para determinar el valor óptimo de kkk, analizando la tasa de error en el rango de k=1k=1k=1 a k=40k=40k=40.
3. Resultados
3.1. Evaluación inicial
El modelo con k=10k=10k=10 presentó los siguientes resultados:
- Matriz de confusión: permitió observar que la mayoría de las predicciones coincidieron con los valores reales, aunque existieron ciertos falsos positivos y falsos negativos en registros cercanos al umbral de 50 µg/m³.
- Métricas de clasificación:
- Precisión global: ~XX%
- Recall: ~YY%
- F1-score: ~ZZ%
(los valores exactos se generan al ejecutar el código en tu dataset real).
3.2. Selección del mejor K
El análisis del error en función de kkk mostró que la tasa mínima de error se alcanzaba alrededor de k = N vecinos, siendo este el valor óptimo para la predicción.
3.3. Validación con datos de 2025
Al aplicar el modelo entrenado sobre el conjunto de datos de 2025, se observó un desempeño consistente, confirmando la capacidad del modelo para generalizar y clasificar correctamente los niveles de PM10 en periodos futuros.

4. Conclusiones
- El modelo KNN resultó adecuado para la clasificación binaria de la calidad del aire en función de las concentraciones diarias de PM10.
- La elección de kkk tiene un impacto significativo en el desempeño: valores bajos tienden a sobreajustar, mientras que valores altos suavizan en exceso la clasificación.
- Los resultados sugieren que el modelo puede emplearse como herramienta de apoyo para identificar días de riesgo en términos de calidad del aire.
- Se recomienda complementar este enfoque con técnicas de validación cruzada y considerar la incorporación de más variables ambientales (temperatura, humedad, velocidad del viento) para mejorar la precisión.
5. Referencias
- Bishop, C. M. (2006). Pattern Recognition and Machine Learning. Springer.
- Han, J., Kamber, M., & Pei, J. (2012). Data Mining: Concepts and Techniques. Elsevier.
- U.S. Environmental Protection Agency (EPA). Air Quality System (AQS) Data. Disponible en: https://www.epa.gov/airdata

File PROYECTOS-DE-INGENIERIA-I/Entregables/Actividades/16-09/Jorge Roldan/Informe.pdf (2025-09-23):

Informe Final: Modelado y Predicción de PM10 mediante Regresión Lineal

Alumno: Jorge Roldan Montalvan

Curso: Proyectos de Ingeniería I

### 1. Introducción

La contaminación atmosférica representa uno de los principales retos ambientales y de salud pública en la actualidad. Entre los contaminantes más relevantes se encuentra el material particulado respirable PM10 (partículas con diámetro menor a 10 micrómetros), el cual puede ingresar al sistema respiratorio y generar diversas enfermedades cardiovasculares y respiratorias.

El objetivo de este trabajo fue analizar la evolución histórica de la concentración de PM10 y construir modelos de regresión lineal simple y múltiple que permitan predecir su comportamiento en el año 2025. A través de estos modelos se busca no solo generar un análisis estadístico, sino también aportar un insumo para la toma de decisiones en el ámbito ambiental.

### 2. Metodología

Para el desarrollo del estudio se trabajó con un conjunto de datos que contiene registros diarios de contaminantes y del Índice de Calidad del Aire (AQI). El flujo de trabajo incluyó las siguientes etapas:

1. Definición de la variable objetivo:
Se seleccionó como target la variable Daily Mean PM10 Concentration, dado que representa directamente el nivel de contaminación atmosférica.
2. Regresión lineal simple:
En una primera aproximación se utilizó únicamente el mes como predictor. Esto permitió analizar la tendencia estacional y observar si existía una relación lineal básica entre el tiempo y los niveles de PM10.
3. Regresión lineal múltiple:
Posteriormente se incluyeron otras variables predictoras, tales como el Daily AQI Value, el día del mes y otras características temporales. Este enfoque permitió capturar mejor las variaciones de PM10 y mejorar la capacidad explicativa del modelo.
4. Entrenamiento y validación:
Se dividieron los datos en conjuntos de entrenamiento y prueba mediante train-test split, lo cual permitió medir el desempeño real del modelo en datos no utilizados durante el entrenamiento.
5. Métricas de evaluación:
Se emplearon indicadores como el R² (coeficiente de determinación), el RMSE (Root Mean Squared Error) y el MAE (Mean Absolute Error), además del cálculo de porcentajes de error relativos para validar la precisión de las predicciones.

El procesamiento y modelado se realizaron en Python, utilizando librerías como pandas, scikit-learn, matplotlib y seaborn.

### 3. Resultados

- En la regresión lineal simple, el modelo obtuvo un coeficiente de determinación R² ≈ 0.125, lo que indica que explica alrededor del 12.5% de la variabilidad de los datos. Además, se obtuvieron valores de MAE ≈ 5.06 µg/m³ y RMSE ≈ 5.97 µg/m³, lo cual refleja que el modelo presenta un error moderado en la estimación de los niveles de PM10.
- En la regresión lineal múltiple, al incorporar variables adicionales como el Daily AQI Value, se observó una mejora en la capacidad predictiva, obteniendo un R² superior al modelo simple y un menor error en las métricas de validación (MAE y RMSE).
- El análisis de los residuos mostró que la mayoría de los errores se distribuyeron de forma aceptable, aunque con algunas desviaciones esperables en datos ambientales que suelen ser ruidosos.

### 4. Predicción al año 2025

Con base en el modelo múltiple, se estimaron los niveles mensuales de PM10 para el año 2025. Los resultados indican que:

- La concentración de PM10 se mantendría dentro de un rango similar al observado en años previos, con una tendencia a incrementarse en determinados meses.
- La comparación con los valores reales observados en los primeros nueve meses del 2025 mostró un error porcentual promedio aceptable, lo que refuerza la validez del modelo.

Sin embargo, es importante considerar las limitaciones de los modelos lineales:

- No capturan relaciones no lineales complejas entre las variables.
- No anticipan cambios externos como nuevas regulaciones ambientales, alteraciones climáticas o variaciones en el tráfico vehicular.

Por lo tanto, los resultados deben interpretarse como una aproximación estimada y no como una predicción absoluta.

### 5. Conclusiones

- La regresión lineal simple es útil para identificar una primera relación entre tiempo y contaminación, pero resulta insuficiente para explicar la complejidad del fenómeno.
- La regresión múltiple se ajusta mejor a los datos y permite obtener predicciones más confiables al considerar múltiples factores.
- El error promedio en la proyección del 2025 se mantuvo dentro de rangos razonables, lo que indica que el modelo puede ser una herramienta de apoyo en la vigilancia ambiental.

- A futuro, sería recomendable explorar modelos más avanzados, como regresión polinómica, Random Forest o técnicas de Machine Learning, que podrían capturar patrones no lineales y mejorar la capacidad predictiva.

Figura 1. Serie temporal histórica de PM10 (2023–2024).
Se observa la evolución diaria de la concentración de partículas PM10 en el periodo 2023–2024. La gráfica permite identificar patrones estacionales y fluctuaciones propias de la dinámica ambiental.

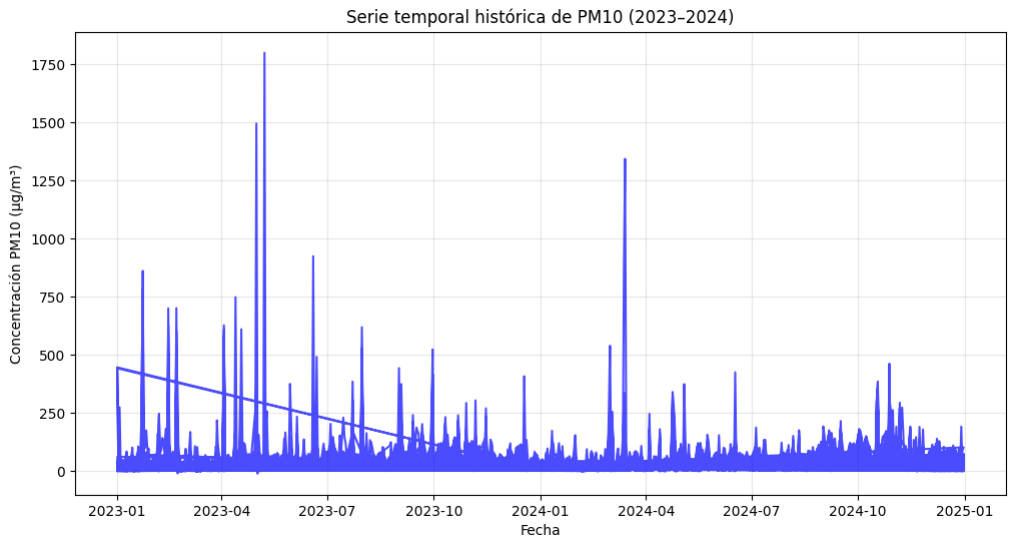
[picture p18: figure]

Figura 2. Ajuste del modelo de regresión lineal múltiple.
Resultados del modelo múltiple, mostrando una mayor cercanía de los puntos a la línea ideal, lo que indica un mejor desempeño.

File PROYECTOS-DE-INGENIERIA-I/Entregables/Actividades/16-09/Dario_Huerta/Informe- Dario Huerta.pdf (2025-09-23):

## Análisis y Regresión Lineal del Conjunto de Datos de Atención Médica 🏥

El informe se basa en un modelo de regresión lineal simple y múltiple, que busca encontrar una relación entre las variables independientes (características del paciente, como edad y género) y la variable dependiente, que en este caso es el resultado de la prueba (Test Results Num).

Preprocesamiento de los Datos

Antes de construir el modelo, se realizaron varias transformaciones en el conjunto de datos:

- Codificación de Género: La variable Gender (género) se convirtió de categorías de texto ("Male", "Female") a valores numéricos (0 para "Male" y 1 para "Female").
- Codificación One-Hot: Se aplicó la codificación one-hot a las variables categóricas Medical Condition, Insurance Provider y Medication. Este método crea nuevas columnas binarias (con valores True o False), una por cada categoría, lo que permite que el modelo de regresión las interprete como características numéricas.
- Codificación de Resultados de Pruebas: La variable objetivo Test Results (resultados de pruebas) se mapeó a valores numéricos, creando la columna Test Results Num con la siguiente correspondencia:
- "Normal" -> 0
- "Inconclusive" -> 1
- "Abnormal" -> 2
- Selección de Características: Se eliminaron las columnas que no eran relevantes o no eran numéricas para la regresión, como nombres, fechas, detalles del médico y el hospital, y las variables categóricas originales que ya fueron codificadas. Las características (X) y la variable objetivo (y) se prepararon para el modelo.

Construcción y Entrenamiento del Modelo

El conjunto de datos se dividió en dos partes:

- Conjunto de Entrenamiento (70%): Utilizado para ajustar el modelo, es decir, para que el algoritmo de regresión aprenda la relación entre las características y el resultado de la prueba.
- Conjunto de Prueba (30%): Utilizado para evaluar el rendimiento del modelo con datos que no ha visto antes, lo que proporciona una estimación más realista de su capacidad de predicción.

Se utilizó el modelo LinearRegression de la biblioteca scikit-learn para realizar el análisis. Al entrenar el modelo, se obtuvieron los coeficientes para cada característica, los cuales indican la relación y la importancia de cada una de ellas para predecir el resultado de la prueba.

Resultados y Evaluación del Modelo

Coeficientes y Estadísticas

Los coeficientes del modelo muestran el impacto de cada característica en la predicción. Sin embargo, en este caso, la mayoría de los coeficientes, a excepción de Test Results Num, son extremadamente cercanos a cero. Esto se debe a que la variable objetivo (Test Results Num) ya estaba incluida en el conjunto de características (X). Esto hace que el modelo de regresión sea perfecto, ya que predice la variable objetivo a partir de sí misma.

La regresión lineal es perfecta (R2=1.0), lo cual es un resultado irreal que indica que la variable objetivo (y) está contenida en el conjunto de características (X).

Métricas de Evaluación

- R2 (R-cuadrado): El valor de R2 es 1.0. Un valor de 1.0 significa que el modelo explica el 100% de la variabilidad en los datos de la variable objetivo. Como se mencionó anteriormente, este es un resultado perfecto, pero incorrecto, que surge de un error en la selección de las variables.
- MAE, MSE, RMSE: Los valores de los errores MAE (Error Absoluto Medio), MSE (Error Cuadrático Medio) y RMSE (Raíz del Error Cuadrático Medio) son extremadamente cercanos a cero, lo que también es una consecuencia del error de preprocesamiento, indicando que las predicciones del modelo son casi idénticas a los valores reales.

Visualizaciones

Los gráficos de dispersión y de residuos confirman un resultado perfecto:

- Gráfico de dispersión de y_test vs. predictions: Los puntos forman una línea recta perfecta de 45 grados, mostrando que cada valor predicho coincide con el valor real.
- Histograma de residuos: La distribución de los errores muestra una única barra muy alta en cero, lo que significa que no hay errores o son insignificantes, lo que no es un resultado típico en la mayoría de los problemas de regresión.

Conclusión y Recomendación

El análisis de regresión lineal en este informe demuestra un error crítico de preprocesamiento: la variable objetivo Test Results Num se incluyó accidentalmente como una de las características (X). Por lo tanto, el modelo simplemente aprendió a predecir el valor de y directamente a partir de la misma variable, lo que resulta en un ajuste perfecto, pero completamente sin sentido.

Para que el análisis sea válido, se debe eliminar la columna Test Results Num del conjunto de características X antes de entrenar el modelo. Una vez corregido este paso, el modelo de regresión lineal podrá encontrar la verdadera relación entre las características del paciente (como edad, género, condición médica, etc.) y los resultados de las pruebas,

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
ficie

n

t

e

s, m

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
aliz

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
flej

e

n

u

n

r

e

n

dimie

n

t

o

r

e

alis

t

a
y

ú

til.

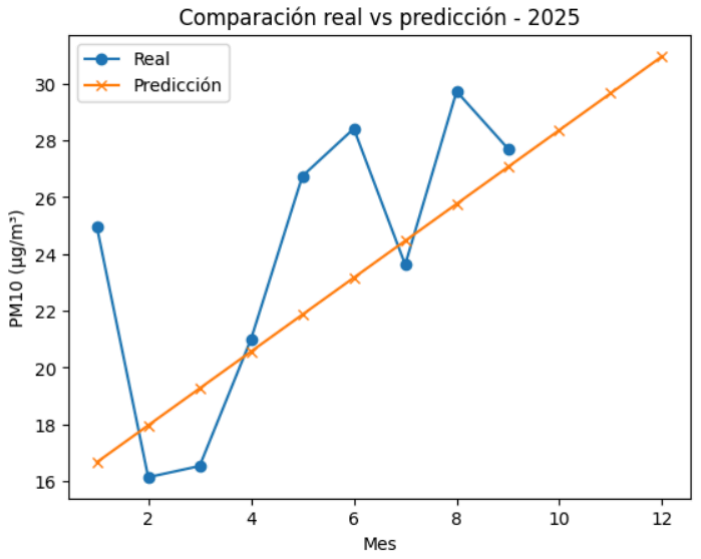
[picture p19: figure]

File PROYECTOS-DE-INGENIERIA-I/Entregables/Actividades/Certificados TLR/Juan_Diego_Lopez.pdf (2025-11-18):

# CONSTANCIA DE PARTICIPACIÓN

Se otorga a:

JUAN DIEGO LOPEZ VEGA

Por finalizar satisfactoriamente el curso MOOC:

Gestión de la madurez tecnológica : TRL (Technology readiness levels)

Esfuerzo: 20 horas
Noviembre 16, 2025, 7:49 pm Brindado por CONCYTEC a través de la Plataforma Vincúlate

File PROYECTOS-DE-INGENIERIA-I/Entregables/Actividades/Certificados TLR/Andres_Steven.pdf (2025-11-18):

# CONSTANCIA DE PARTICIPACIÓN

Se otorga a:

Andres Rodas

Por finalizar satisfactoriamente el curso MOOC:

Gestión de la madurez tecnológica : TRL (Technology readiness levels)

Esfuerzo: 20 horas
Noviembre 18, 2025, 12:43 pm Brindado por CONCYTEC a través de la Plataforma Vincúlate

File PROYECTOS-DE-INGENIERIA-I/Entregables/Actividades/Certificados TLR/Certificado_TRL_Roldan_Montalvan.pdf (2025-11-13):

# CONSTANCIA DE PARTICIPACIÓN

Se otorga a:

Jorge Roldan

Por finalizar satisfactoriamente el curso MOOC:

Gestión de la madurez tecnológica : TRL (Technology readiness levels)

Esfuerzo: 20 horas
Noviembre 12, 2025, 9:57 pm Brindado por CONCYTEC a través de la Plataforma Vincúlate

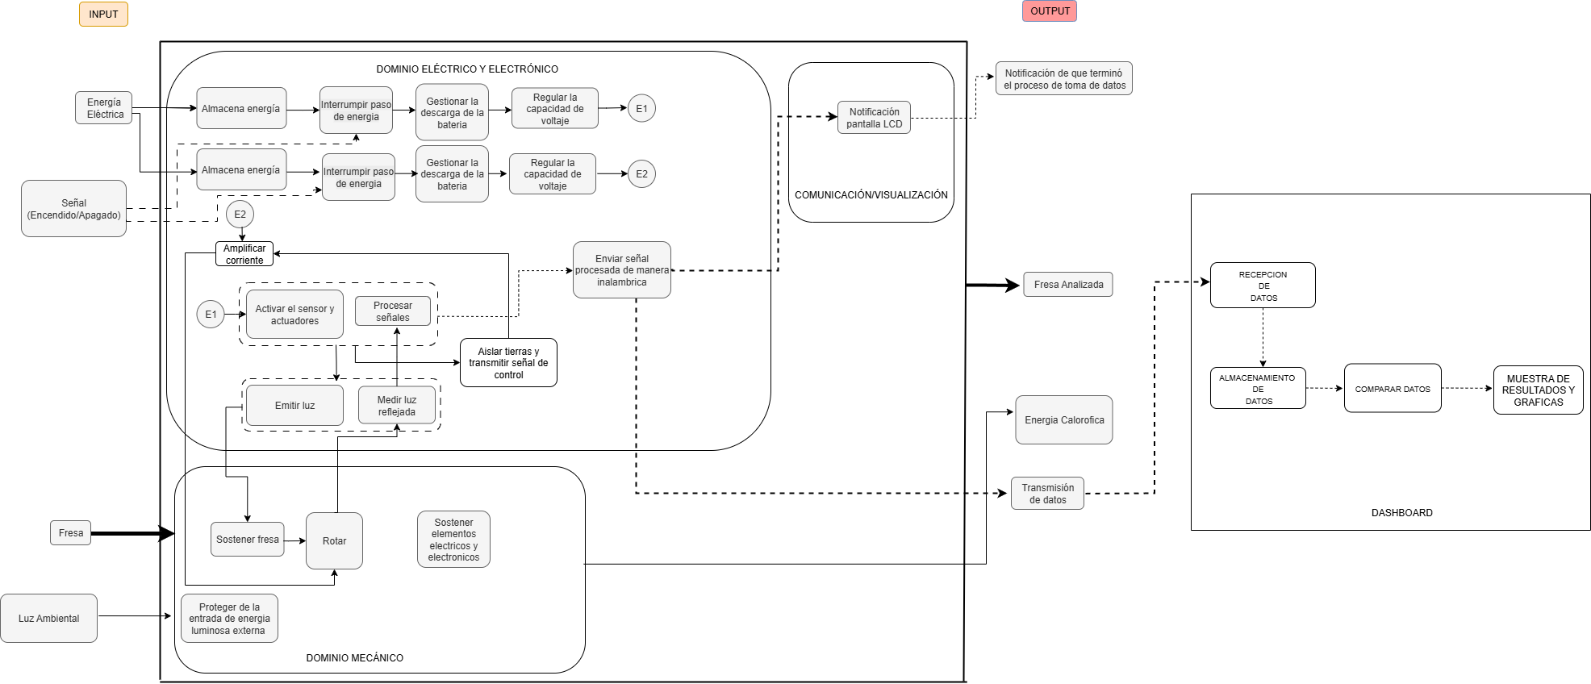
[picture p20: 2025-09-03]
PROYECTOS-DE-INGENIERIA-I/Imagenes/EsquemaFin.drawio.png

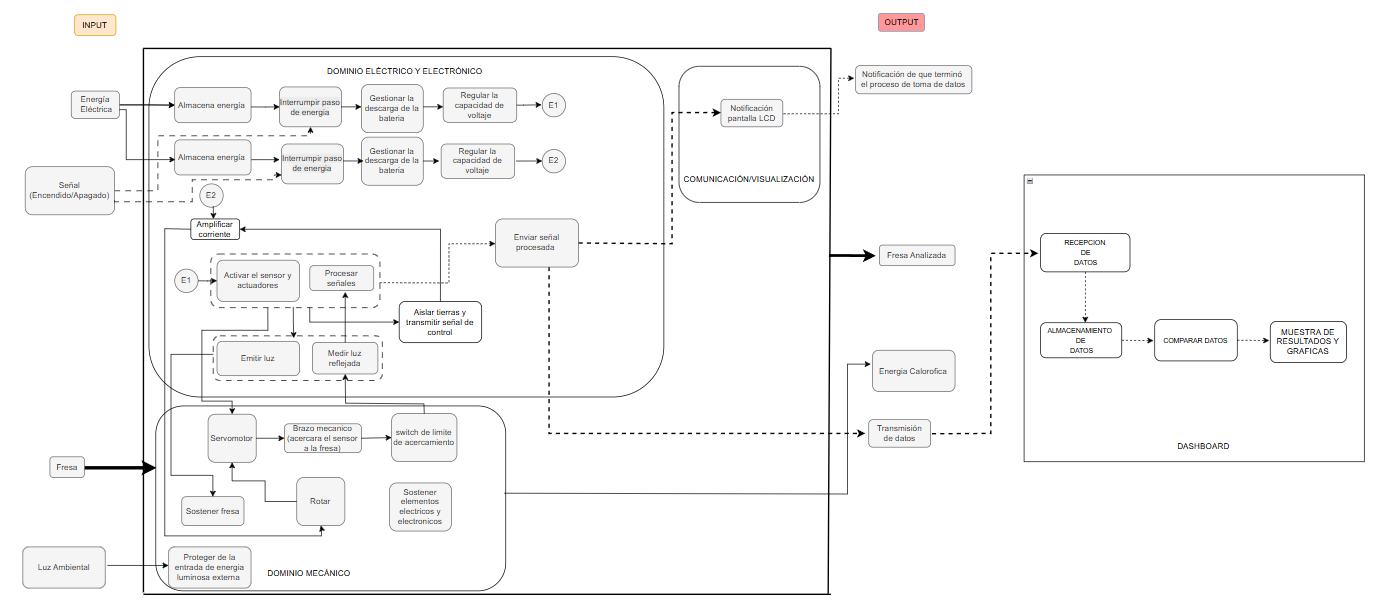
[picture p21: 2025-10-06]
PROYECTOS-DE-INGENIERIA-I/Imagenes/esquema_funciones.png

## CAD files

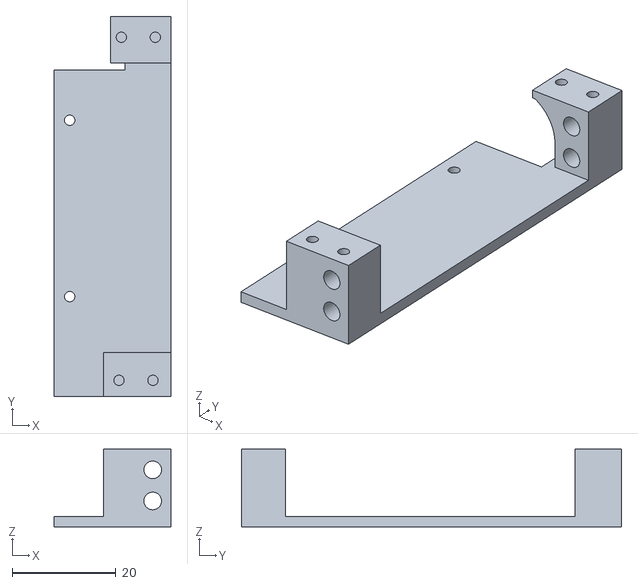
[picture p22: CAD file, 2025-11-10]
PROYECTOS-DE-INGENIERIA-I/Entregables/Partes3d/Base/Base.stl
22.5 x 73.2 x 15.0

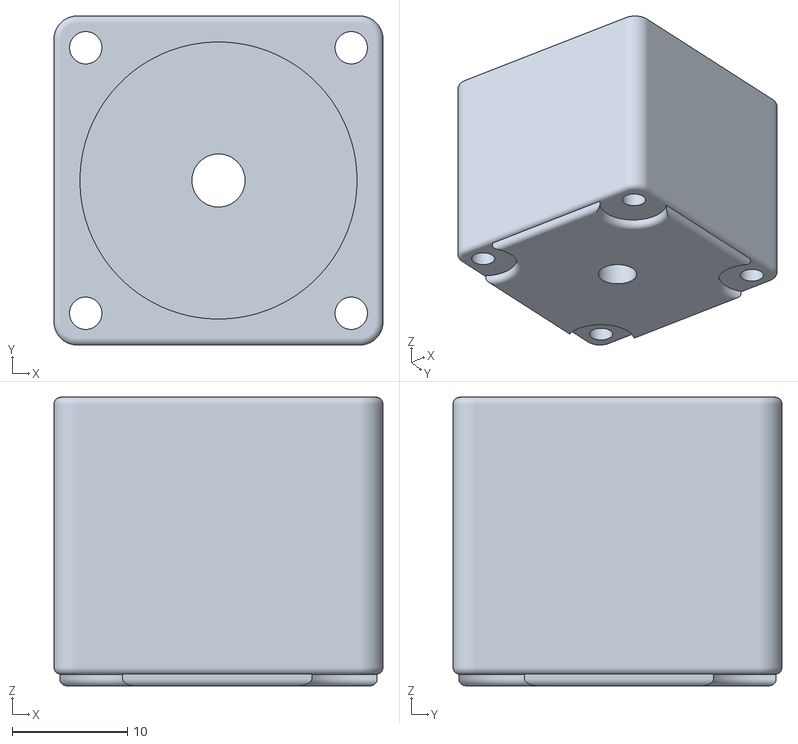
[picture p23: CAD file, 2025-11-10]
PROYECTOS-DE-INGENIERIA-I/Entregables/Partes3d/Caja_StepMotor/CAJA STEP-MOTOR.stl
28.5 x 28.5 x 25.0

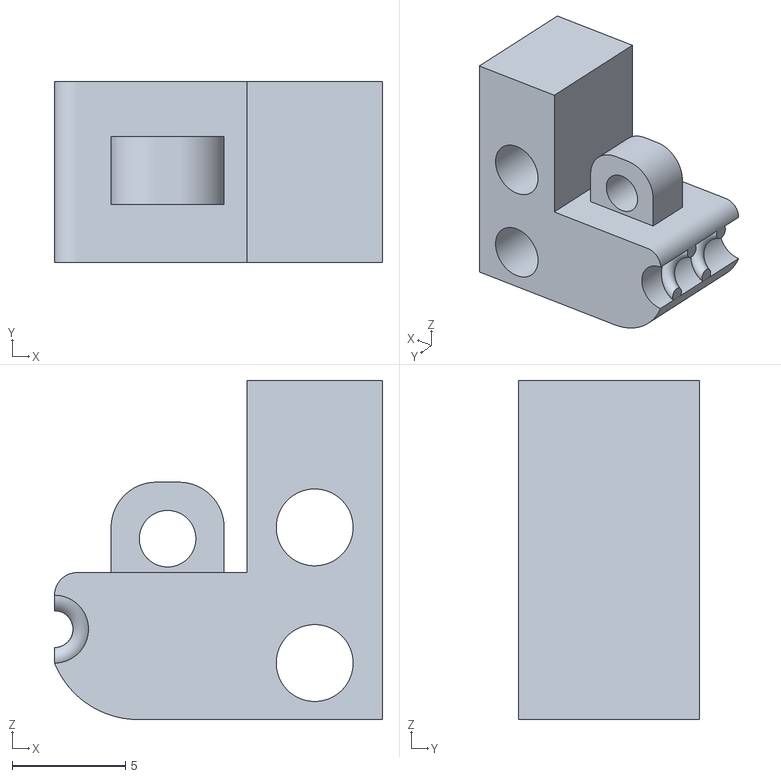
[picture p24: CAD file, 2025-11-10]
PROYECTOS-DE-INGENIERIA-I/Entregables/Partes3d/Corredora/Corredera.stl
14.5 x 8.00 x 15.0

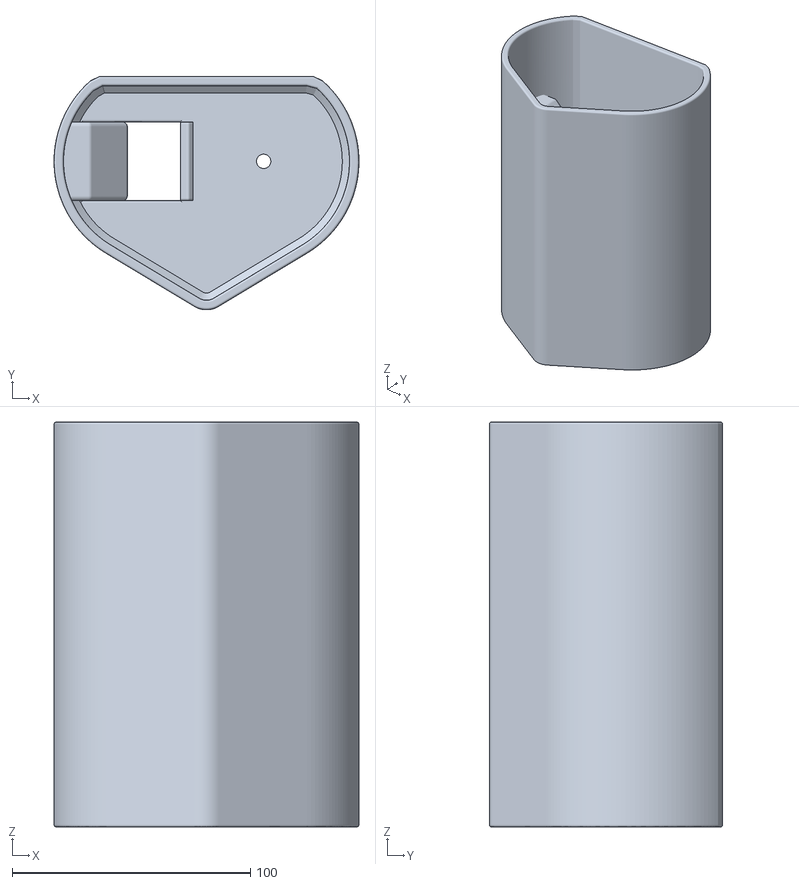
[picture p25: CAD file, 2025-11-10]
PROYECTOS-DE-INGENIERIA-I/Entregables/Partes3d/Parte_Interna/PARTE INTERNA VERSION FINAL.stl
128.0 x 98.0 x 170.0

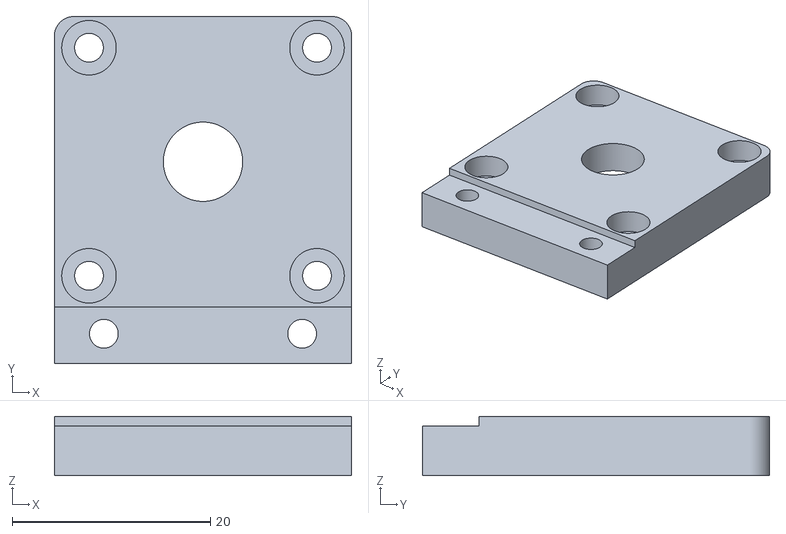
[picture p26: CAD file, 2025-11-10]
PROYECTOS-DE-INGENIERIA-I/Entregables/Partes3d/Tapa_StepMotor/TAPA STEP-MOTOR.stl
30.0 x 35.0 x 6.00

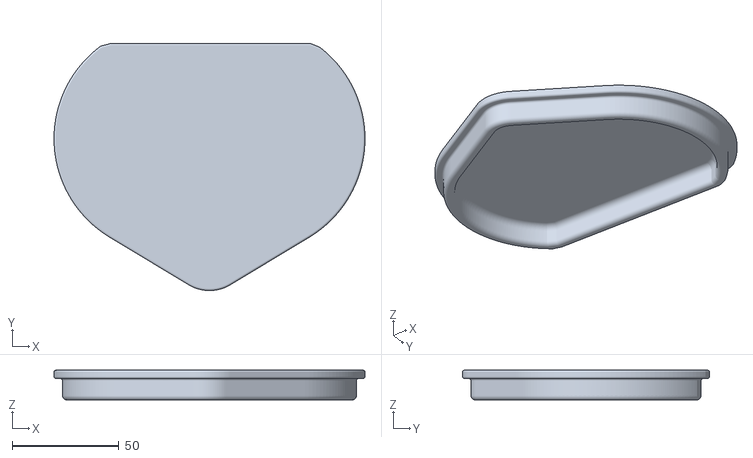
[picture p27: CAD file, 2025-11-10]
PROYECTOS-DE-INGENIERIA-I/Entregables/Partes3d/Tapa_Sup/Inf/PI - TAPA SUPERIOR E INFERIOR CAJA.stl
146.0 x 116.0 x 14.0

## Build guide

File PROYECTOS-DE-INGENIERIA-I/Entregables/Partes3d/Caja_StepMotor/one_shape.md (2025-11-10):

https://cad.onshape.com/documents/bc2641749c4b4dd052690316/w/b36505b3b4374446a7bc18ac/e/640f03230aaea91cd17671e2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

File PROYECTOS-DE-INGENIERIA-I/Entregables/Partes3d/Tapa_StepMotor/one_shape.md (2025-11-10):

https://cad.onshape.com/documents/03424081b9901187dddaa058/w/8114a6a6d8aab699b0f5403f/e/04c22b4accbed42f745c49bb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

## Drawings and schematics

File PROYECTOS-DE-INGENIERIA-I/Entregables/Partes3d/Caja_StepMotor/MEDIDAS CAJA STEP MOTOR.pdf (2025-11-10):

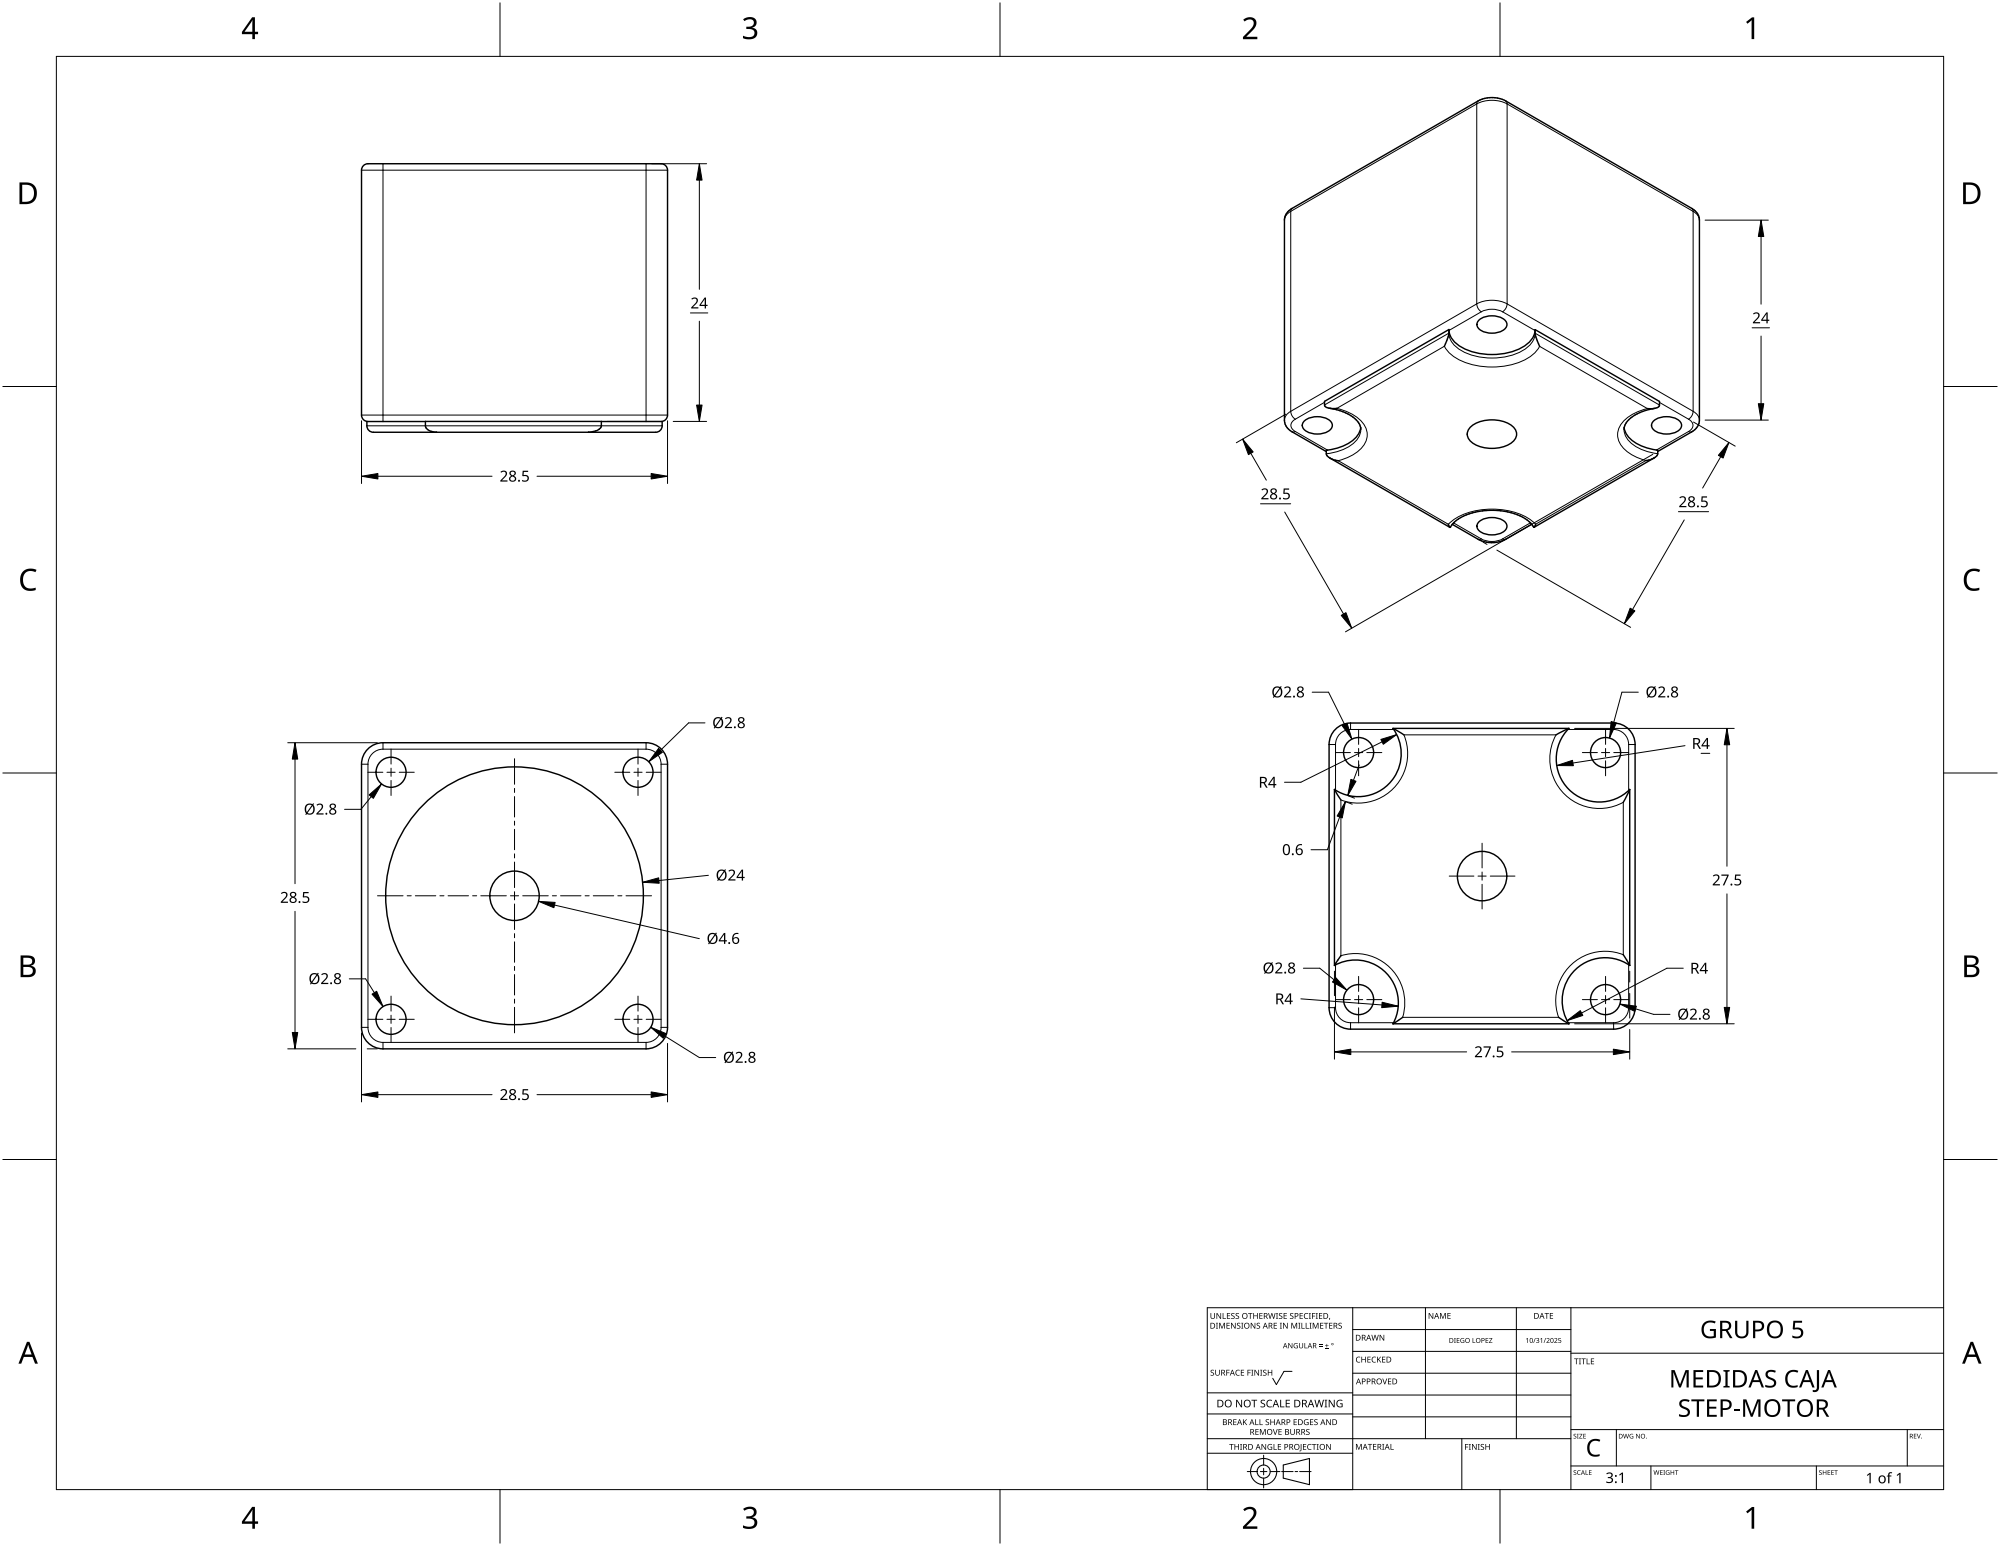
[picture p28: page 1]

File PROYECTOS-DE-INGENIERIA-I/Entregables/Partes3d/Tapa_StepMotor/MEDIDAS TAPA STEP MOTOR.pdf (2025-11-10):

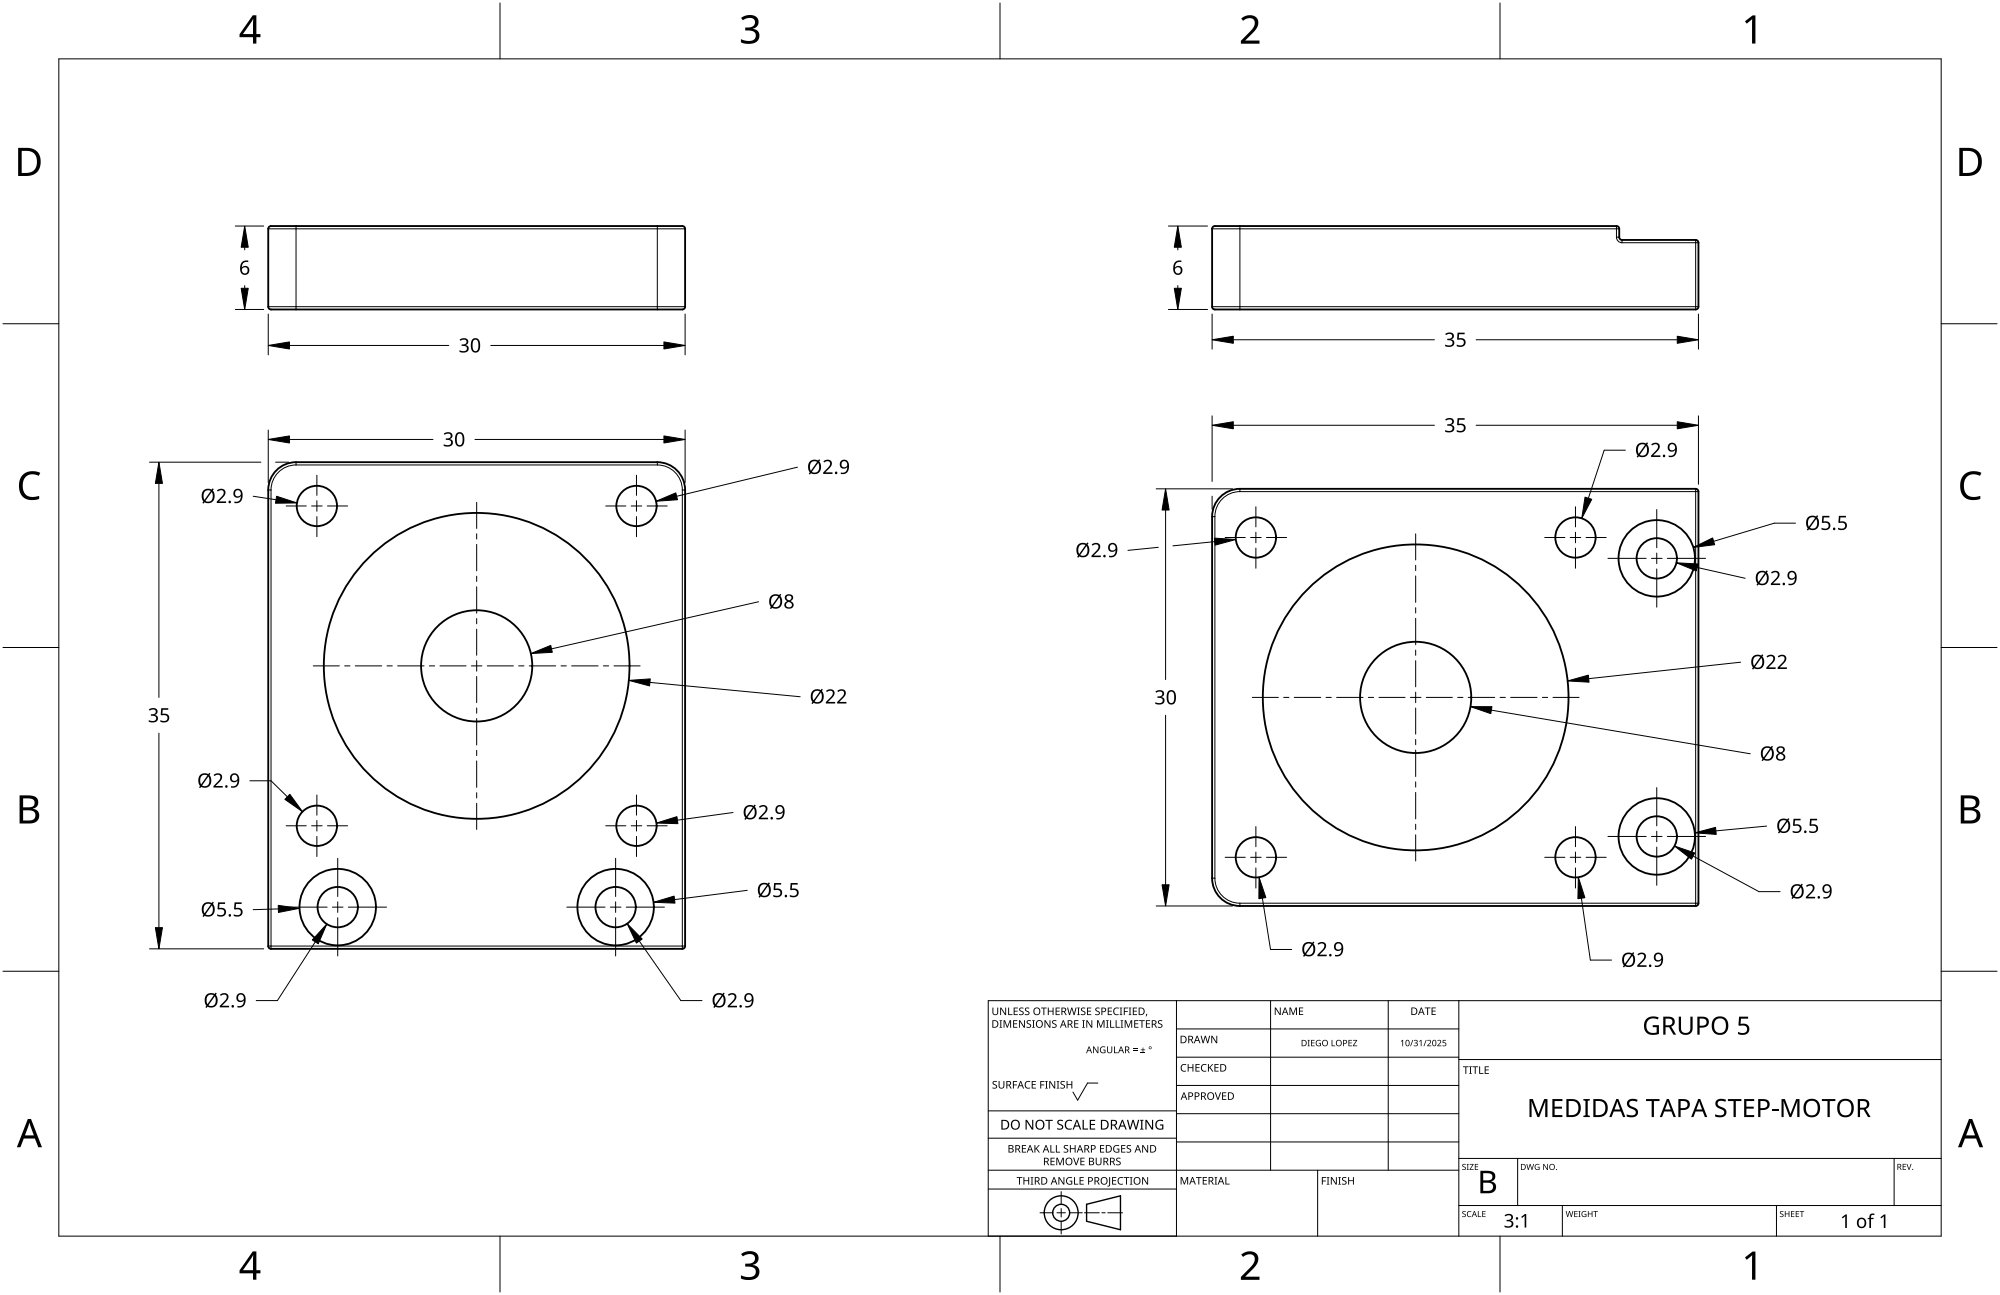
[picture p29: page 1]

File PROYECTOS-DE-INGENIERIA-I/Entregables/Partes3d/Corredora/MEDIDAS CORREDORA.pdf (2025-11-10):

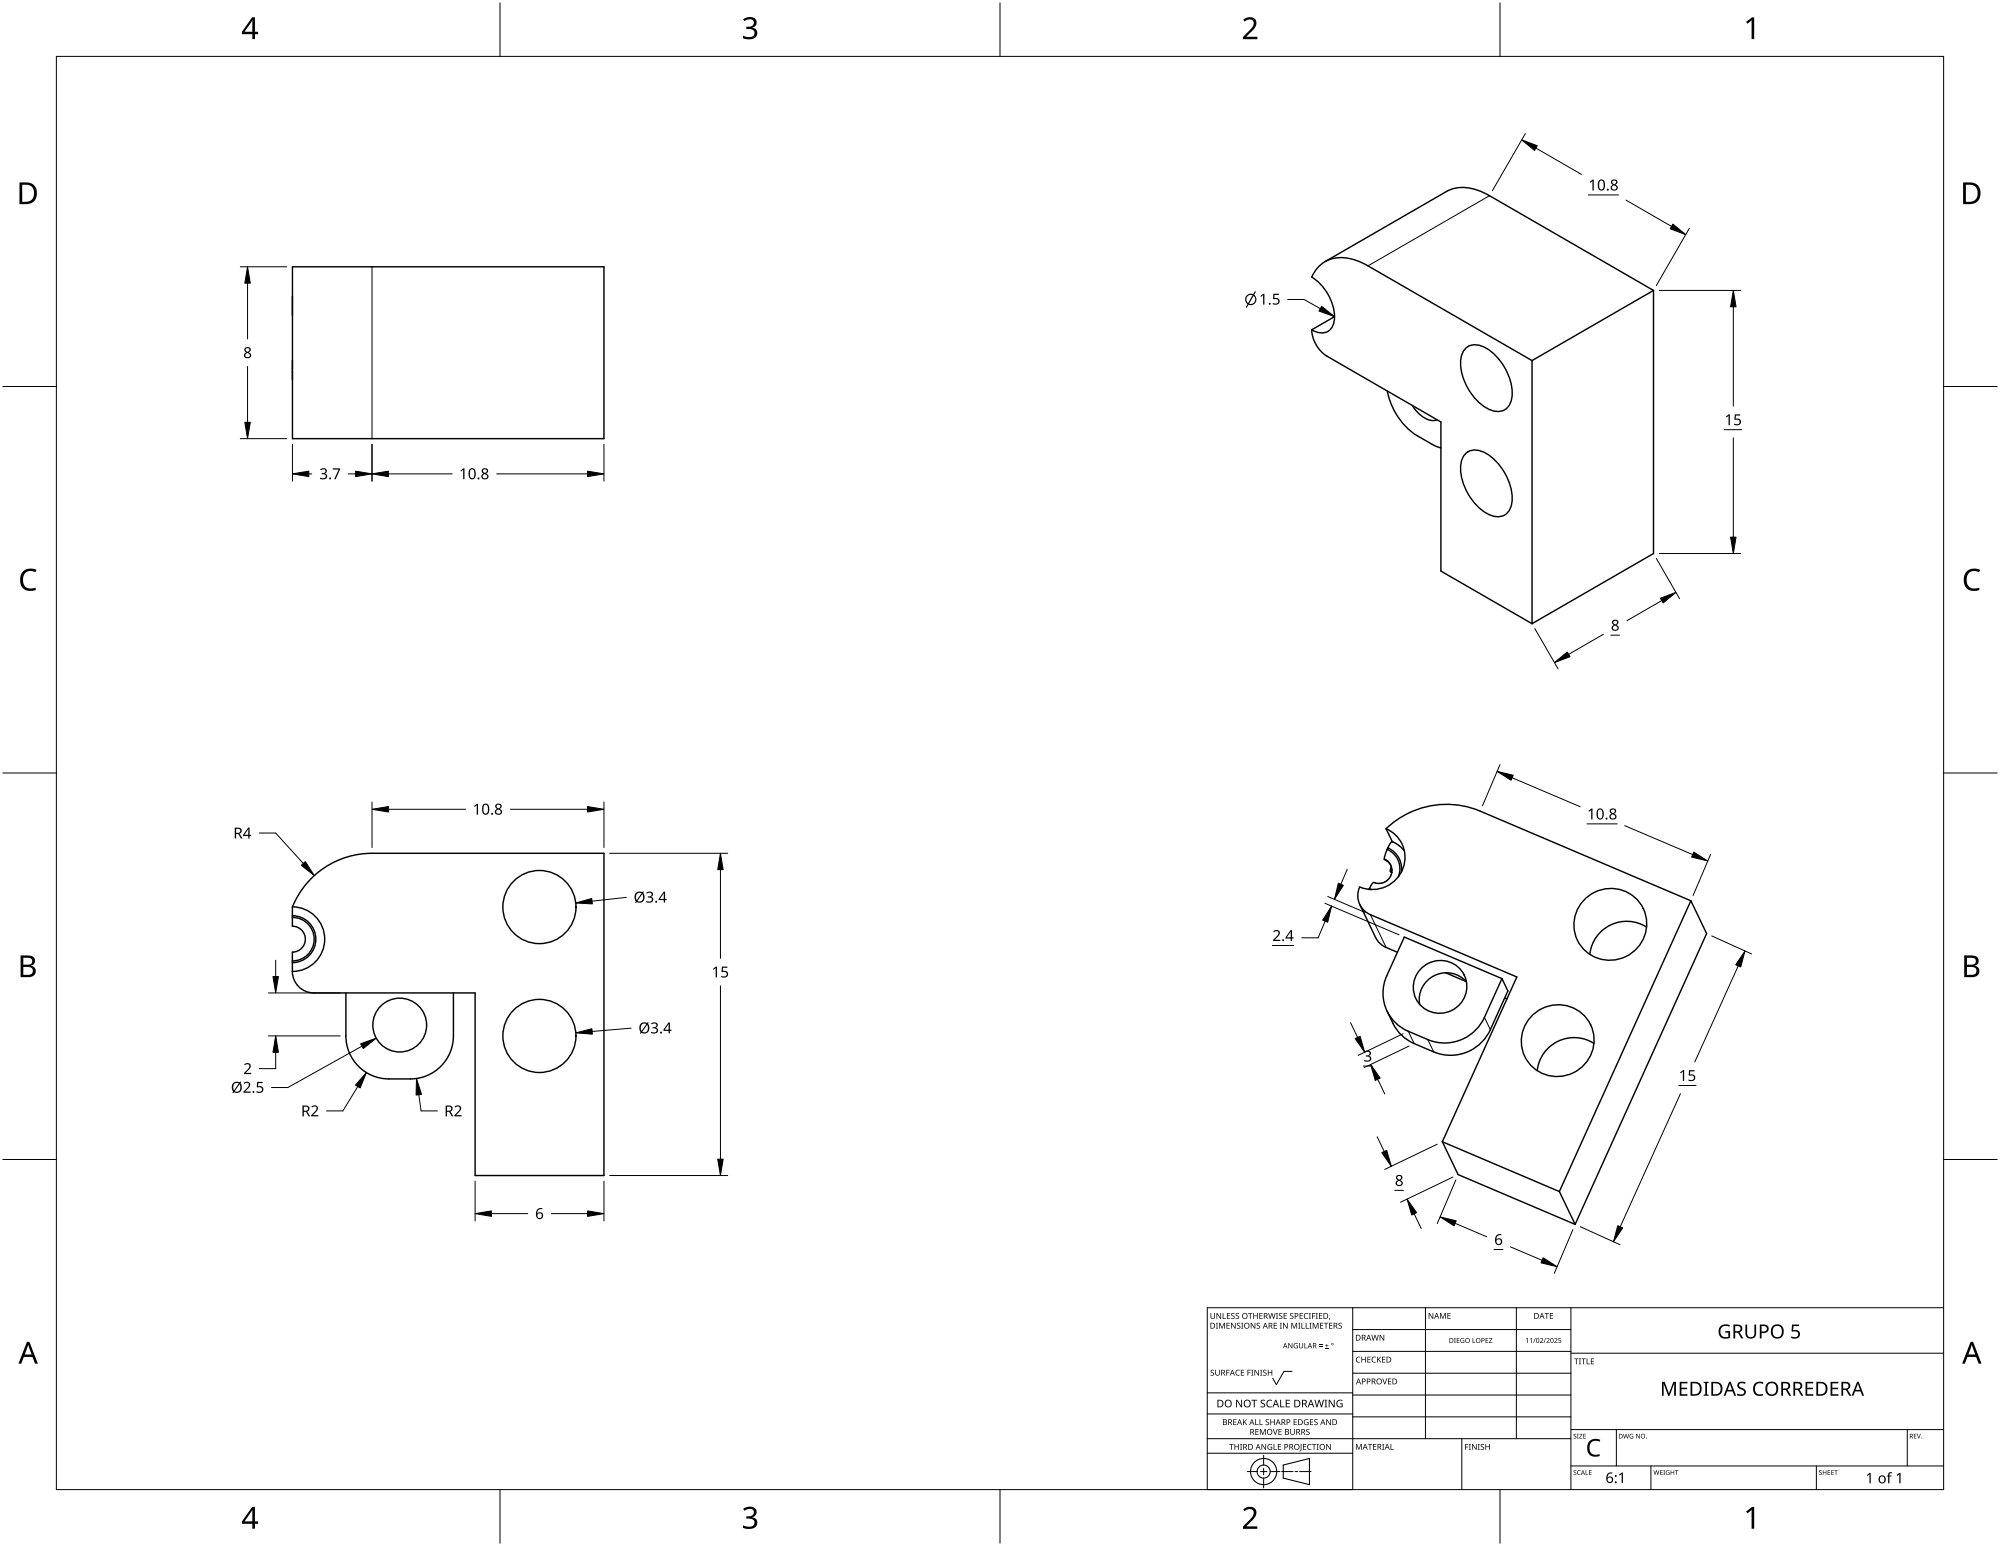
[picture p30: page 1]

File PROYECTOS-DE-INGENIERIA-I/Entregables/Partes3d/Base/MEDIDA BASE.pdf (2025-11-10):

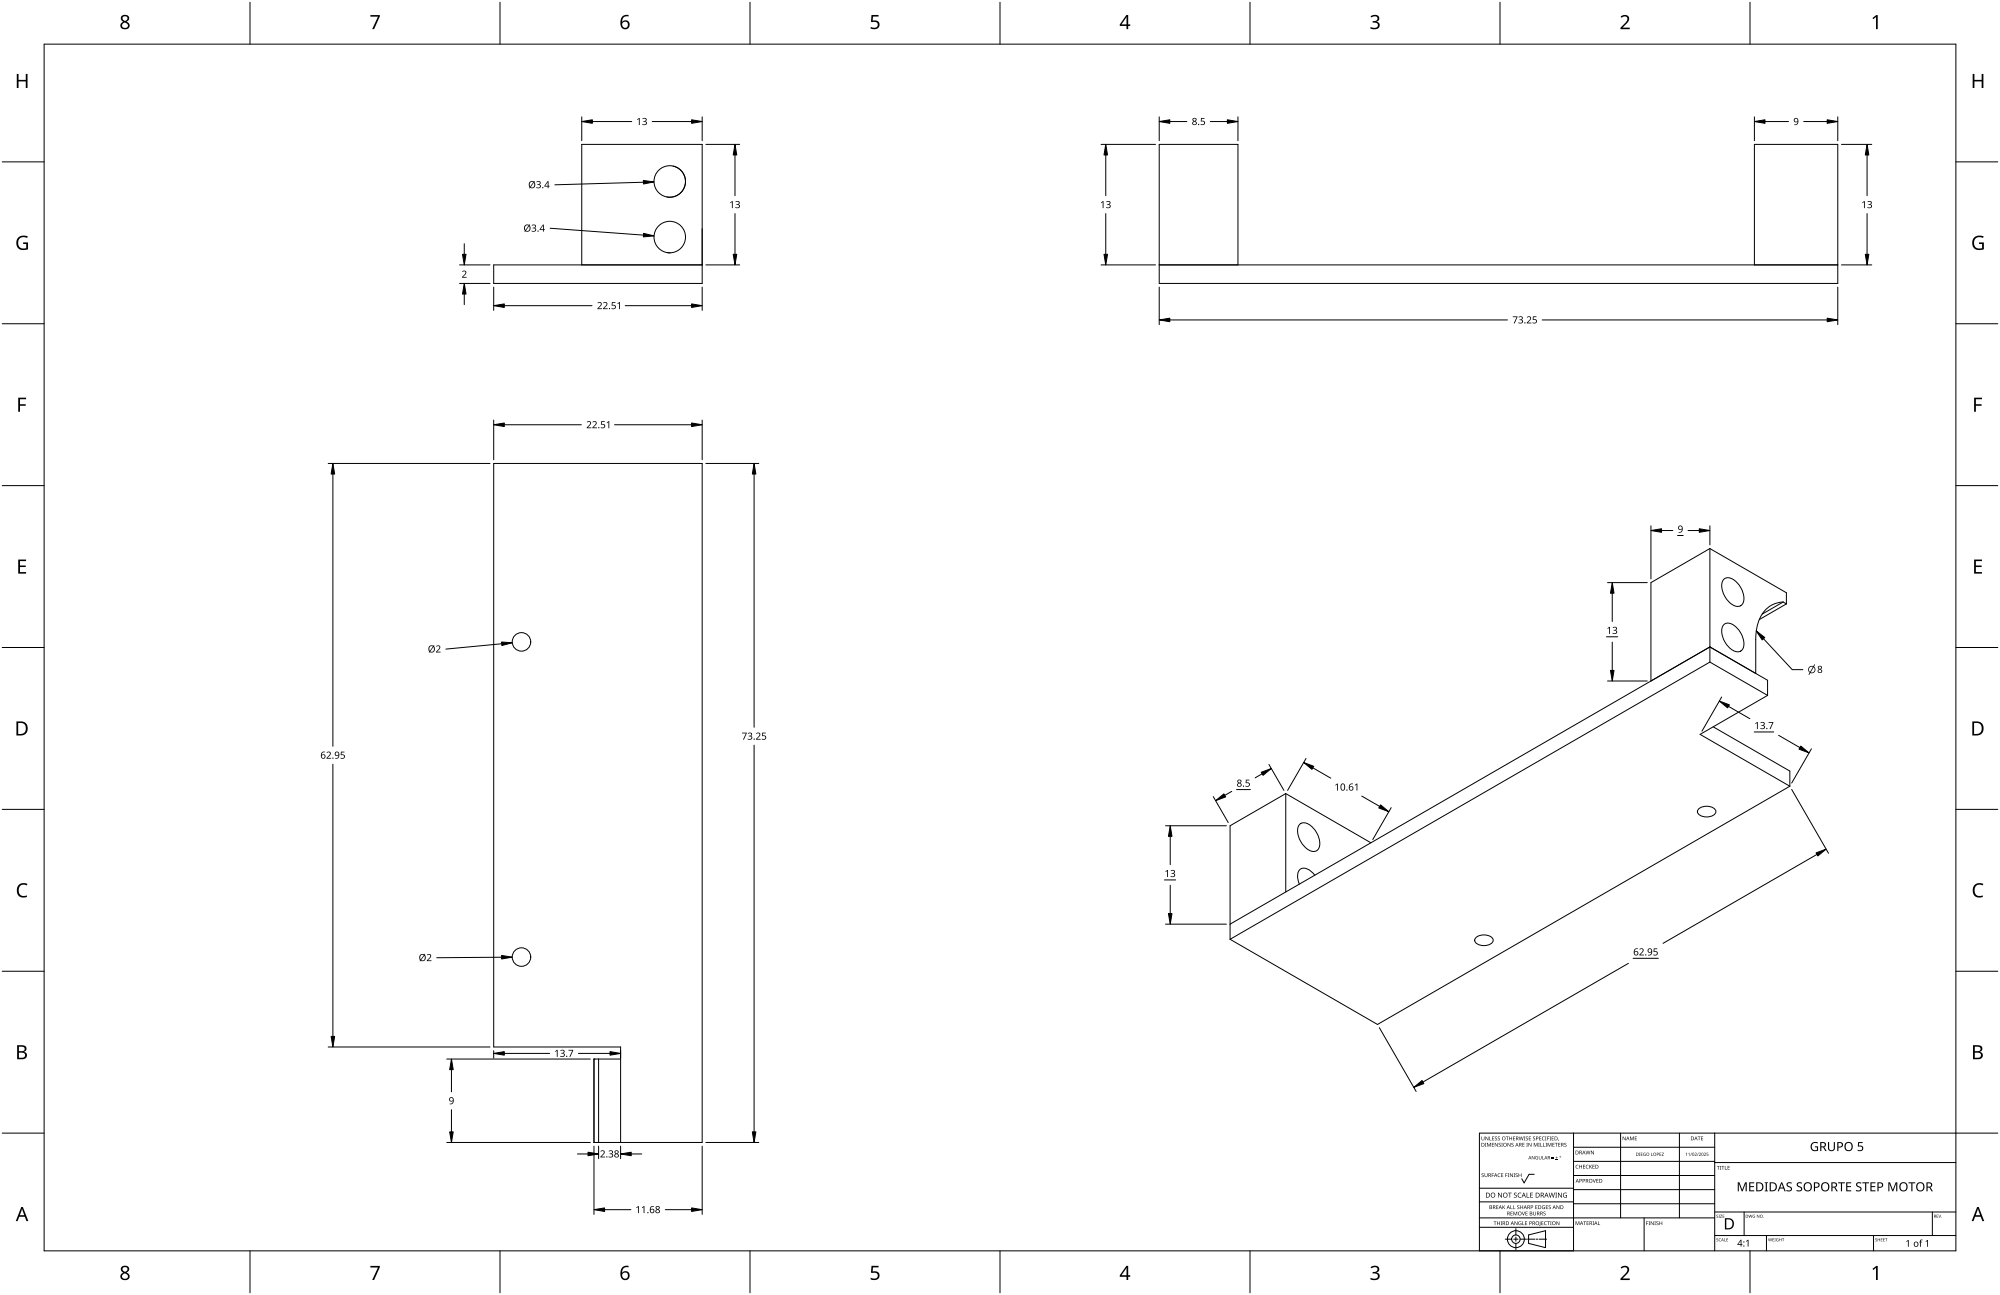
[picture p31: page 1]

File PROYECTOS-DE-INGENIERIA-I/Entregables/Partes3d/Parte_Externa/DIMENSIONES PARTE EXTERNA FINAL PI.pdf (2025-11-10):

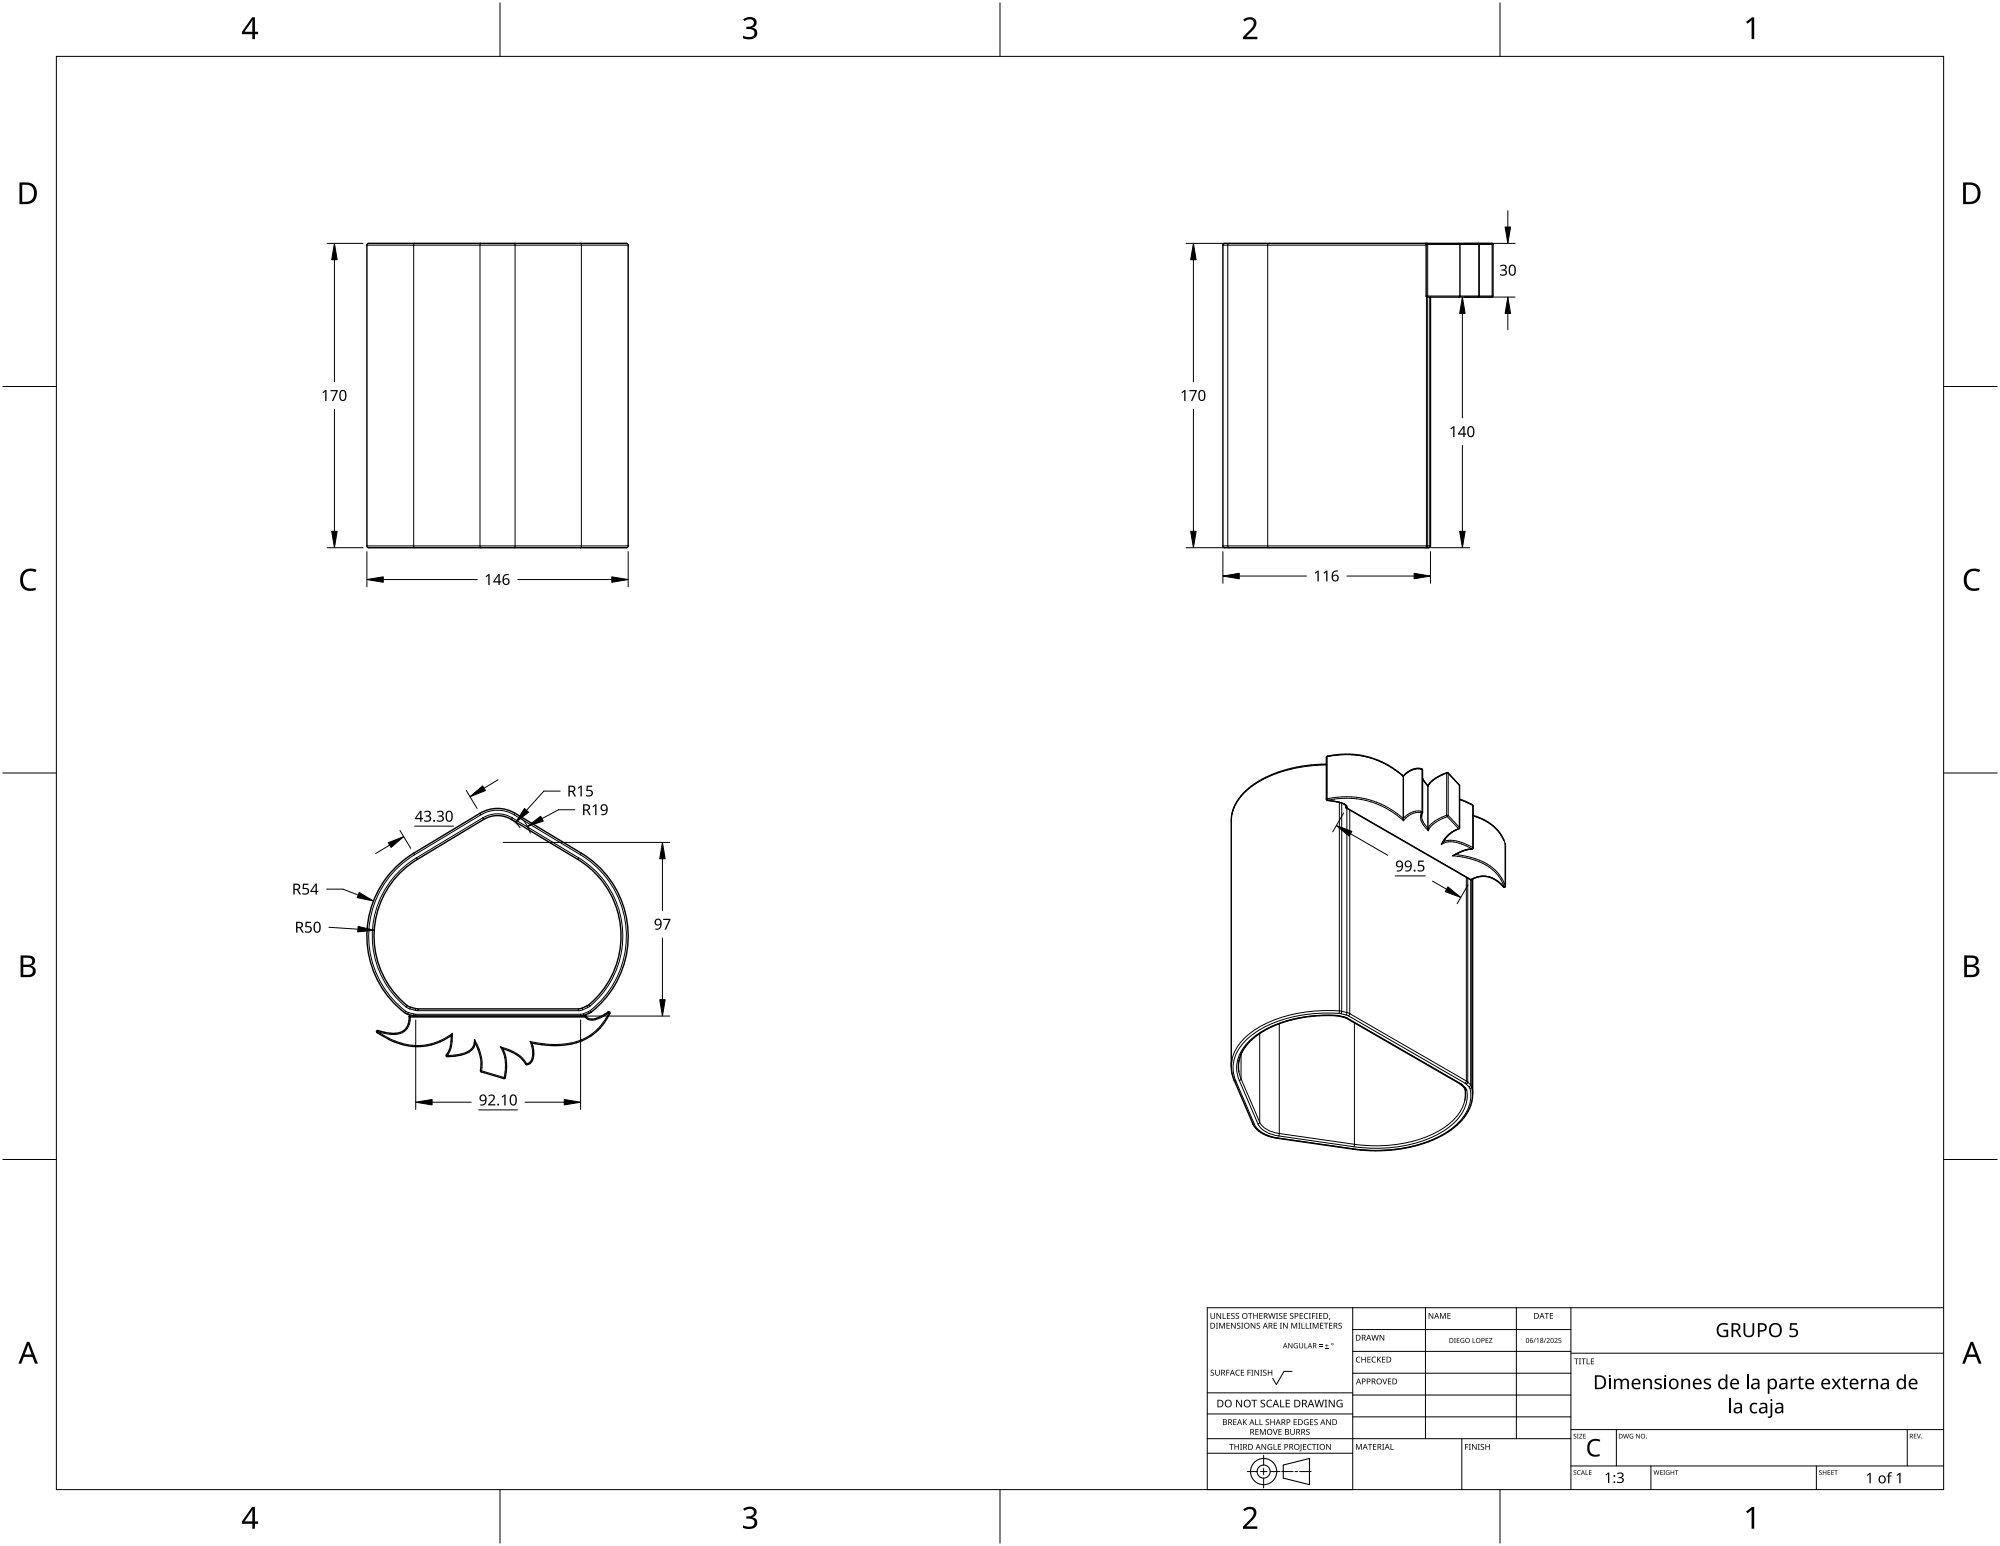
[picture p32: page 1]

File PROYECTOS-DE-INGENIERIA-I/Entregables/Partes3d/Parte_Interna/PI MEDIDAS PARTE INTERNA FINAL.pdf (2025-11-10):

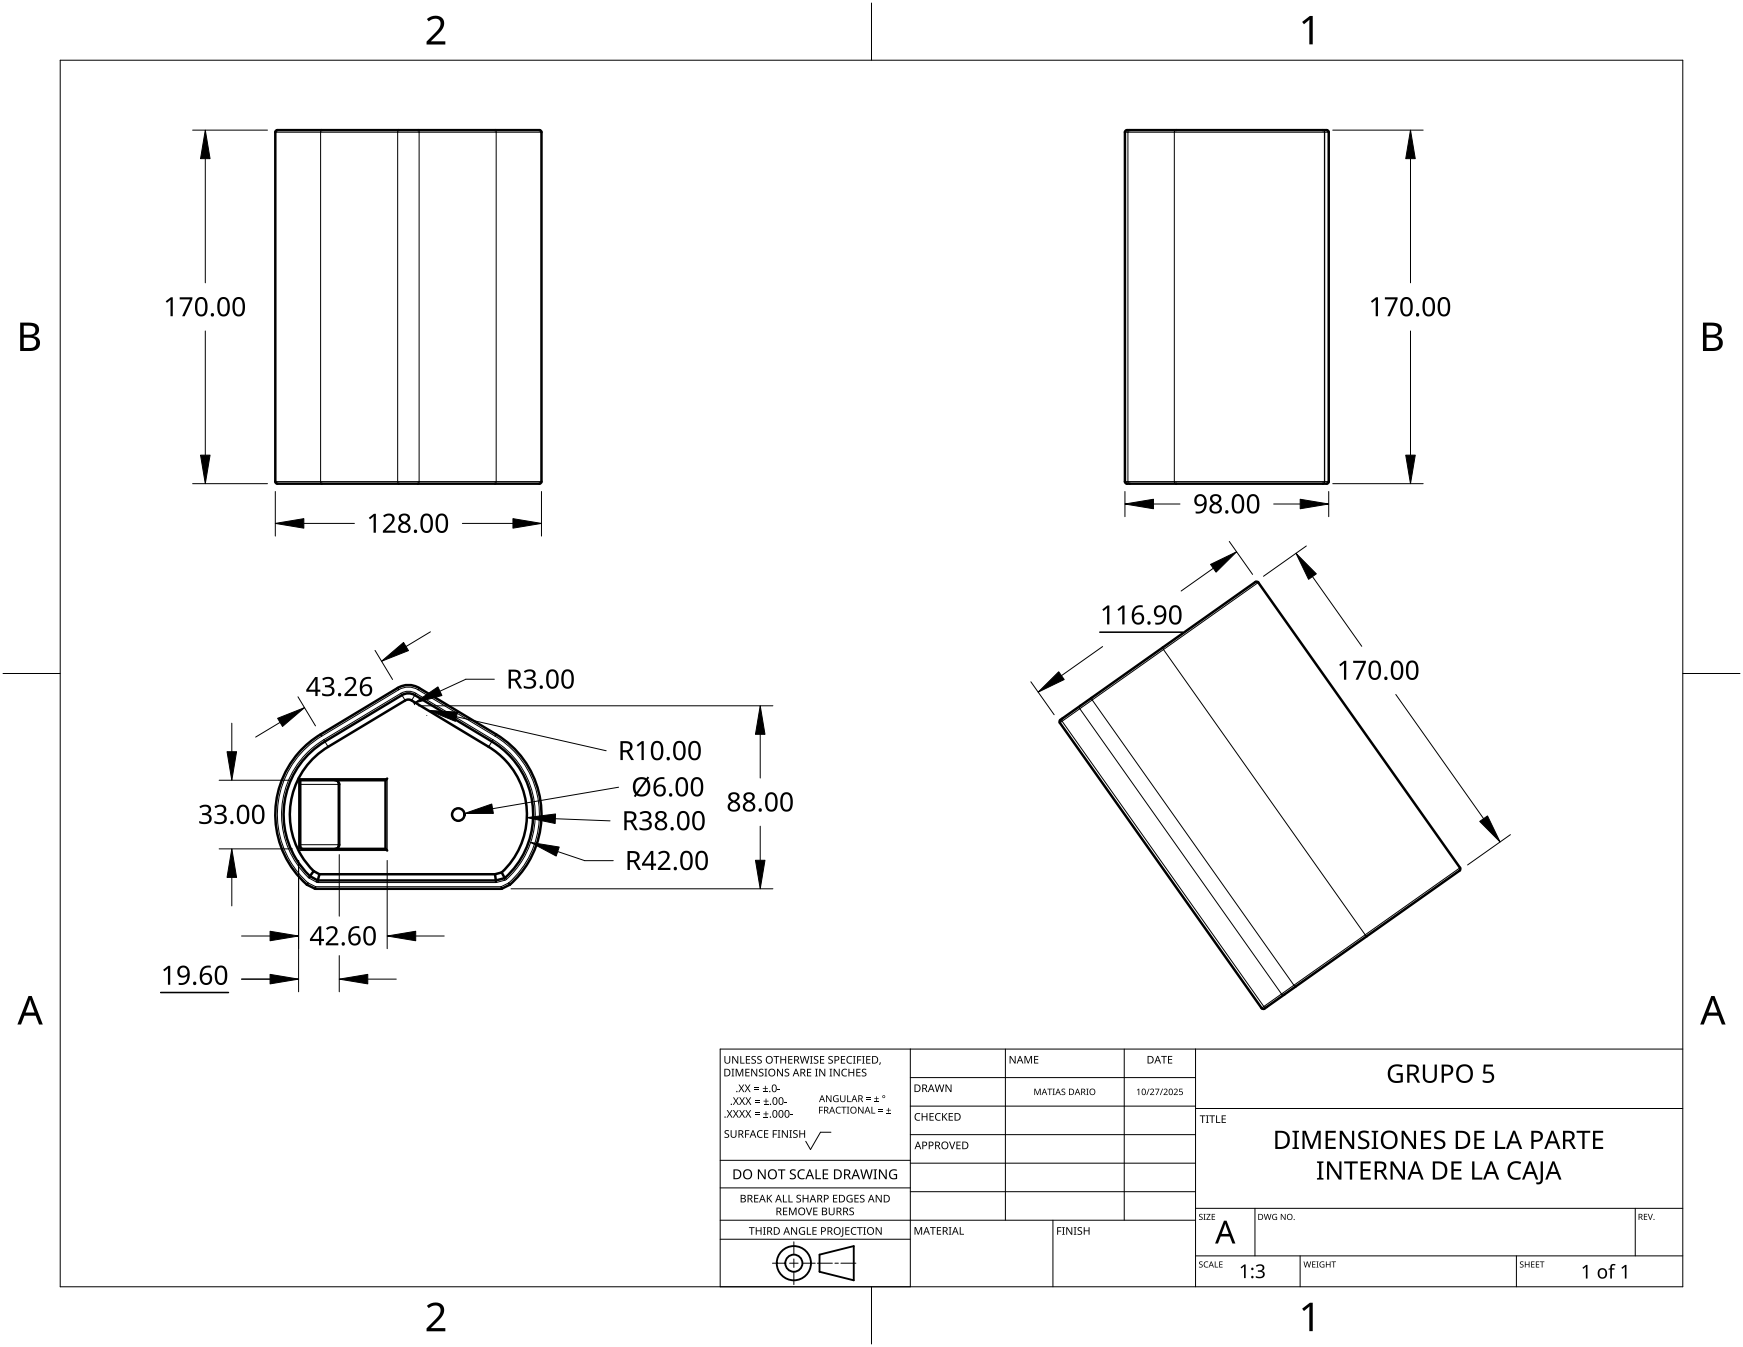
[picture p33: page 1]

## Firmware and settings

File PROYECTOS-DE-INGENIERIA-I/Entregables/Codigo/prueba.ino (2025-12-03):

#include <AccelStepper.h> //CODIGO BUENO
#include <SparkFun_AS7343.h>
#include <Wire.h>

// ==========================================
// 1. CONEXIONES (ESP32)
// ==========================================
// MOTOR Z (Actuador) -> Pines: 26, 25, 33, 32
#define Z_IN1 26
#define Z_IN2 25
#define Z_IN3 33
#define Z_IN4 32

// MOTOR R (Giro) -> Pines: 13, 12, 14, 27
// OJO: Si no prende, desconecta el pin 12 un momento.
#define R_IN1 13
#define R_IN2 12
#define R_IN3 14
#define R_IN4 27

// SENSOR I2C -> Pines: 21, 22
#define I2C_SDA 21
#define I2C_SCL 22

// ==========================================
// 2. OBJETOS Y VARIABLES
// ==========================================
AccelStepper actuator(AccelStepper::FULL4WIRE, Z_IN1, Z_IN3, Z_IN2, Z_IN4);
AccelStepper rotaryMotor(AccelStepper::FULL4WIRE, R_IN1, R_IN3, R_IN2, R_IN4);
SfeAS7343ArdI2C mySensor;

// CONFIGURACIÓN DE MOVIMIENTO
const int NIVELES_Z = 3;               // Total de alturas (Pisos)
const long PASOS_ENTRE_NIVELES = 120; // Distancia para subir de piso SE CAMBIO DE 2000 A 100 3/12
const int PUNTOS_POR_VUELTA = 12;      // Cuántas lecturas por giro completo
const int PASOS_POR_GIRO = 170;        // Pasos para girar al siguiente punto

// Variables internas
int nivelActual = 0;
int puntoActual = 0;
uint16_t data[18]; // Buffer para datos del sensor

void setup() {
  Serial.begin(115200);
  Wire.begin(I2C_SDA, I2C_SCL);

  // Configuración de Motores
  actuator.setMaxSpeed(600);
  actuator.setAcceleration(200);
  rotaryMotor.setMaxSpeed(600);
  rotaryMotor.setAcceleration(200);

  // Pines como salida (para apagado total)
  pinMode(Z_IN1, OUTPUT); pinMode(Z_IN2, OUTPUT); pinMode(Z_IN3, OUTPUT); pinMode(Z_IN4, OUTPUT);
  pinMode(R_IN1, OUTPUT); pinMode(R_IN2, OUTPUT); pinMode(R_IN3, OUTPUT); pinMode(R_IN4, OUTPUT);

  Serial.println("\n\n===================================");
  Serial.println("   INICIANDO SISTEMA DE ESCANEO");
  Serial.println("===================================");

  // --- 1. TEST DE SENSOR ---
  Serial.print("-> Buscando Sensor AS7343... ");
  if (!mySensor.begin()) {
    Serial.println("[FALLO]");
    Serial.println("REVISA CABLES SDA (21) Y SCL (22)");
    while(1); // Se detiene aquí si falla
  }
  Serial.println("[OK]");
  
  // Configuración Sensor
  mySensor.setAgain((sfe_as7343_again_t)8); // Ganancia 256x
  mySensor.enableSpectralMeasurement(true);

  // --- 2. TEST DE MOTORES (Mover un poco y volver) ---
  Serial.print("-> Test Motor Giro... ");
  rotaryMotor.move(100); rotaryMotor.runToPosition();
  rotaryMotor.move(-100); rotaryMotor.runToPosition();
  Serial.println("[OK]");

  Serial.print("-> Test Actuador Z... ");
  actuator.move(100); actuator.runToPosition();
  actuator.move(-100); actuator.runToPosition();
  Serial.println("[OK]");
  
  apagarMotores(); // Enfriar
  delay(1000);
  Serial.println(">>> INICIANDO CICLO DE TRABAJO <<<");
}

void loop() {
  
  // ----------------------------------------
  // FASE 1: MOVER Y MEDIR (ROTACIÓN)
  // ----------------------------------------
  Serial.print("Nivel Z: "); Serial.print(nivelActual);
  Serial.print(" | Angulo: "); Serial.print(puntoActual);
  
  // 1. Mover Motor de Giro
  rotaryMotor.move(PASOS_POR_GIRO);
  rotaryMotor.runToPosition();
  apagarMotores(); // Apagar para que no vibre
  delay(200);      // Estabilizar
  
  // 2. Leer Sensor y Mostrar en Serial
  Serial.print(" -> Midiendo... ");
  leerSensor(); 

  // Avanzar contador de giro
  puntoActual++;

  // ----------------------------------------
  // FASE 2: CAMBIO DE NIVEL (ALTURA)
  // ----------------------------------------
  if (puntoActual >= PUNTOS_POR_VUELTA) {
    // Si terminamos una vuelta completa (12 puntos)
    puntoActual = 0;
    nivelActual++;
    
    if (nivelActual < NIVELES_Z) {
      Serial.println("\n>>> SUBIENDO AL SIGUIENTE NIVEL... <<<");
      
      // Calcular nueva altura absoluta
      long nuevaAltura = nivelActual * PASOS_ENTRE_NIVELES;
      actuator.moveTo(nuevaAltura);
      actuator.runToPosition();
      
      apagarMotores();
      delay(1000); // Esperar a que deje de temblar
      
    } else {
      // SI YA TERMINAMOS TODOS LOS NIVELES
      Serial.println("\n\n===================================");
      Serial.println("   ESCANEO COMPLETO - REGRESANDO");
      Serial.println("===================================");
      
      mySensor.ledOff();
      
      // Regresar a cero ambos motores
      actuator.moveTo(0);
      while(actuator.distanceToGo() != 0) actuator.run();
      
      rotaryMotor.moveTo(0);
      while(rotaryMotor.distanceToGo() != 0) rotaryMotor.run();
      
      apagarMotores();
      Serial.println("SISTEMA EN ESPERA.");
      while(1); // Detener ejecución aquí
    }
  }
}

// ==========================================
// FUNCIONES DE AYUDA
// ==========================================

void leerSensor() {
  // Encender LED, Leer, Apagar
  mySensor.setLedDrive(10); // 10mA
  mySensor.ledOn();
  delay(50);
  
  mySensor.readSpectraDataFromSensor();
  mySensor.getData(data);
  
  mySensor.ledOff();

  // IMPRIMIR DATOS VISIBLES
  // Solo mostramos 3 canales clave para no saturar la pantalla
  Serial.print("[F1-Azul: "); Serial.print(data[0]);
  Serial.print("] [F5-Verde: "); Serial.print(data[4]);
  Serial.print("] [F8-Rojo: "); Serial.print(data[7]);
  Serial.println("]");
}

void apagarMotores() {
  // Corta la energía para enfriar drivers y motor
  digitalWrite(Z_IN1, LOW); digitalWrite(Z_IN2, LOW); 
  digitalWrite(Z_IN3, LOW); digitalWrite(Z_IN4, LOW);
  digitalWrite(R_IN1, LOW); digitalWrite(R_IN2, LOW); 
  digitalWrite(R_IN3, LOW); digitalWrite(R_IN4, LOW);
}

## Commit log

2025-08-19 creacion de carpeta de proyectos de ingenieria
2025-08-19 creacion de carpeta Entregables
2025-08-19 creacion de carpeta Imagenes
2025-08-25 creacion de carpeta Actividades y subcarpeta 25-08
2025-08-25 creacion de readme en la carpeta Actividades
2025-08-25 creacion de carpetas de lo integrantes para la actividad del dia 25-08
2025-08-25 se añadio la imagen diego.png a la carpeta imagenes
2025-08-25 creacion de carpeta imagenes_primera_actividad
2025-09-16 crear carpeta 16-09 para subir las actividades de los integrantes
2025-09-16 subir carpeta de diego
2025-12-01 prueba codigo, motor y arduino
2025-12-03 Refactor motor and sensor setup for ESP32
    Updated motor and sensor configurations for new hardware setup.
